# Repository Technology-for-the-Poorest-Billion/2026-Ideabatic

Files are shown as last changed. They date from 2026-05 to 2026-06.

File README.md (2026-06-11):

# IDEABATIC -Uniform Cooling Solutions

This is our team's Git Repository for our project.

Our team worked with IDEABATIC to investigate a non-uniform cooling issue within the SMILE Go vaccine carrier, a cooling device designed to transport vaccines safely in remote regions with limited access to refrigeration. Previous testing had shown that vaccines stored in the upper compartments of the carrier were consistently warmer than those in the lower compartments, potentially reducing vaccine effectiveness and storage life. To understand the causes of this temperature asymmetry, we developed a custom temperature-monitoring system and conducted a series of experiments investigating factors such as ice pack geometry, natural convection, door heat ingress, and thermal contact within the cooler. Our results showed that no single factor was solely responsible for the cooling imbalance, but that multiple interacting mechanisms likely contribute to the problem. The most effective passive solution was a redesigned ice pack insert, which reduced the temperature difference by approximately 2°C, while forced airflow using small fans almost completely eliminated the asymmetry. The findings provide valuable insight into the thermal behaviour of the SMILE Go and offer practical recommendations to support the future development of more reliable vaccine transport systems.

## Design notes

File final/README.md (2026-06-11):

# Read Me

This folder includes all the final submission work for the project. This includes individual reports, the group report, and a final video presentation.

## Other files:
- Test Results and Analysis Document
- Thermal Test Data Spreadsheet
- Final Presentation Slides
- Arduino Code for the experimental Setup
- Extensive documentation on convection, materials research, electrical work, and imaging
- CAD files for the bottle inserts

## Note of work distribution
Please note that commit history is not a representative measure of work completed by each team member. Work was collaboratively completed in a Google Drive, and group work completed uniformly between team members. A better measure of individual work would be detailed within individual reports and appropriate crediting.

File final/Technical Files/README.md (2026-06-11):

All CAD files, experimental data spreadsheet, documentation are found in here, **excluding the Test_results_and_analysis.md file.**

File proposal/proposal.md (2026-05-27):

# Problem description

**SMILE** <br>
The SMILE project aims to tackle the challenges associated with last-mile vaccine delivery and user error during transportation and administration. The “last mile” refers to the final stage of the supply chain, where vaccines are transported from storage warehouses to remote villages. Throughout this journey, vaccines must be kept within a strict temperature range of 2–8°C to maintain the cold chain. However, long transport times and improper handling often result in vaccine spoilage. Existing cool box designs present several issues that can compromise vaccine safety. In response, SMILE has been developed as a solution to protect temperature-sensitive vaccines during both transport and administration. The system features a vaccine carousel surroundings a central ice-pack bottle, all enclosed within an insulated hexagonal structure. 

Key features of the SMILE system include:
- A self-closing door to prevent the lid from being accidentally left open during vaccine administration, thereby reducing heat exposure.
- A single ice pack design, which eliminates the risk of using excessive or insufficient ice while remaining chemical-free.
- Separation between the ice pack and the vaccine chamber, protects the vaccines from freezing.

**The problem** <br>
In the SMILE, a single ice pack is used to reduce the risk of improper use and simplify operation. However, this design leads to issues of asymmetric cooling within the vaccine chambers. Thermal testing has demonstrated that the upper vaccine chambers are hotter than the lower chambers in the carousel, leading to non-uniform cooling. Since vaccines need to stay within such the narrow temperature range or 2-8°C, temperature differences will reduce the potential storage duration. By investigating the potential causes of this asymmetry and prototyping potential solutions, we can improve the reliability and extend the cool life of the vaccines. In the original SMILE, additional insulation was added at the top resulting in an asymmetric centre, to counteract heat entering from above. However, the SMILE Go (prototype we are looking at) does not use this design. We are aiming to explore alternative strategies.



# Presentation of the proposal

Through this project, we will investigate the causes of asymmetric cooling in the SMILE GO and explore ideas to reduce this temperature variation. One proposed cause of the variation is the melting behaviour of the horizontal ice pack. As it melts, the cold water accumulates at the bottom, the remaining ice floats on top and there is a air pocket at the top due to the respective densities or air, water and ice. This results in a non-uniform thermal interface to the vaccine carousel, potentially reducing heat transfer to the upper vaccines and therefore leading to the asymmetric cooling seen. Another factor we believe may cause the variation is the formation of natural convection currents within the vaccine carousel chamber.
  
To investigate these effects, thermal experiments and prototype modifications will be conducted to analyse ice melt behaviour and temperature distribution throughout the system. Potential solutions may include redesigning the ice-pack geometry, altering bottle orientation, or introducing internal thermal conduction features to achieve more uniform cooling. By reducing thermal asymmetry, the project aims to improve temperature stability and extend the effective cool life of vaccines during transport and administration.

Over the course of the next few weeks, we will:
- Design & test cooler insert with the aim of reducing the airgap at the top and redistributing the ice in the bottle
- Investigate impact of convection
- Prototype new carousel design to reduce convection

We will first test the existing prototype with temperature sensors to gain control resuts. As we propose design changes, such as the insert or the new carousel, we will perform temperature tests again to investigate if there are significant changes. We will also analyse the trade off between increasing insert volume and decreasing the water content. 

# Assessment of the quality of the proposal

In the wider context, this project will be:
- **Responsible** - The proposal should not cause any harm and we must consider any negative unintended impacts. In order to achieve this we have carefully assessed the materials we are using. We aim to use sustainably sourced or recycled materials which don’t impact workers health. For example, the icepack only contains water (no chemicals) and the icepack bottle is made of HDPE which is widely recyclable.
  
- **Responsive** - this means it responds to a genuine need. There are currently existing solutions to the problem e.g. a standard vaccine cooler, but the SMILE project is an improvement on existing coolers and our proposal would further improve this solution. Our goals and projects aims have been developed in line with talking to our partner Kitty and looking at research she has already conducted. One of the areas Kitty wants addressed is the asymmetric cooling.
  
- **Adds significant value** - Our investigation and potential solutions aim to reduce the asymmetric cooling which would reduce the temperature difference between the top and bottom of the vaccine carousel thereby allowing the vaccinces to remain within the temperature range for longer (longer cool life).
  
- **Accessible to end users** - the modifications we are making would not significantly affect usability as the changes are limited to the ice-pack bottle and the vaccine carousel design. The changes would affect manufacturing. We will keep this accessible by still using 3D printed parts and not adding significantly more parts. Any insert we design should be simple and a potential redesign of the carousel should not decrease its usability
  
- **Context appropriate** - The SMILE project is being developed for use in countries such as Cameroon where the ambient temperature is significantly hotter than the UK so the cooling aspect is more important. Additionally, the aim is for the product to be manufacturable in a makerspace in the country of use, so it should be 3d printable and use accessible materials.

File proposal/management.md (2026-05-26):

# Project Management Plan

## The People
The three members in our team are Karen, Kerry, and Kavita:

Karen (mechanical/electrical engineer)
- Strengths: 3D modelling,3D printing, Drawing
- Weaknesses: Thermal modelling, Hardware

Kerry (mechanical/aerospace engineer)
- Strengths: Thermal/material knowledge, Mechanical design
- Weaknesses: Computational modelling, Electronics

Kavita (mechanical/electrical)
- Strengths: Electronics, 3D printing experience
- Weaknesses: Computational modelling

## The Resources Needed
| Resource | Cost | Source |
|---|---|---|
| PLA printer filament | £10–15 | CUED |
| Ice Bottle | £10 | RS Components |
| Temperature Sensors | £25 | Amazon |
| Arduino Wires | £0 | CUED |
| Laser Cut Wood (Offcuts) | £0 | CUED |
| Hot Glue Sticks | £1 | CUED |

## The Timeline
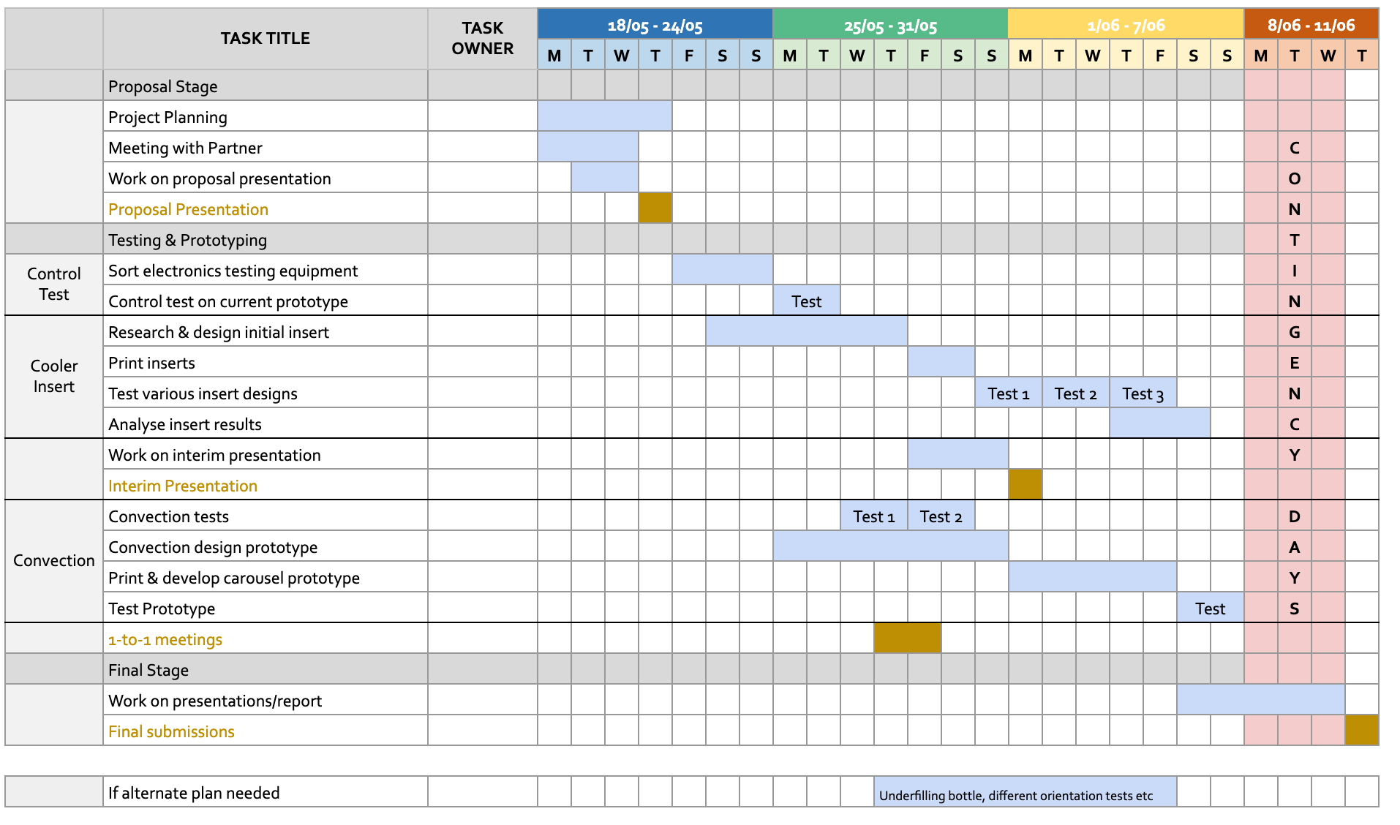
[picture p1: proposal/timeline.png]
Timeline


## Contingency Plans
Our approach to contingency involves a variety of strategies. 
#### Extra Time:
Firstly, extra time has been included in the development timeline at the end of the project. This means that, in the case of delays or unexpected issues during the course of the project, our timeline is be flexibile enough to allow the team to finish any required work on time. This is particularly useful since the plan is to operate a continuous sequence of experiments - any hiccups may lead to cascading delays. The contingency days overlap with the report-writing period, as the work can be carried out flexibly alongside other tasks.

#### Staged Testing Approach:
An important consideration for this experiment-driven project is ensuring that progress is not entirely dependent on a single test outcome. As an example, early in the testing phase, an experiment will be conducted to assess the significance of convection in causing non-uniform cooling. If convection is found to have a substantial effect, the next stage of the project will focus on designing a new vaccine carousel to mitigate natural convection within the cooler. If the effect is minimal, a contingency plan will be implemented involving further investigation into other factors that may contribute to non-uniform cooling. This staged testing approach ensures the progress of this project does not falter given a certain test result.

#### Other Ideas to Investigate:
Given the minimal impact of cooler inserts or convection prevention, some further investigations can be conducted, to provide Kitty and IDEABATIC more information on the SMILE Go. These include:
* The effect of underfilling the bottle - investigating the effect of a larger air bubble on non-uniform cooling.
* Insulation methods and materials - investigating cheap and viable alternatives for SMILE Go manufacture.

#### Reduce risks:
Finally, to avoid project failure for safety reasons, and to maintain teammembers' safety, all members will produce and sign risk assessments for the tools and methods to be used in this project. 

## The Assessment of the Risks and Safety Considerations
### Tooling Risks
#### Effect
* Burns from hot glue guns
* Soldering burns, breathing in toxic fumes
* Fire from laser cutter
* Cuts and incidents from hand tools
#### Mitigation
* Acquire appropriate training
* Make sure fume hood on laser cutter is activated
* Keep hands and skin away from hot surfaces

### Electrical Testing Risks
#### Effect
* Water contact with electrical components
* Overheating of Arduino
#### Mitigation
* Keep electronics away from water
* Keep surfaces dry
* Keep voltages and currents within working range

### 3D Printer Risks
#### Effect
* Cuts from sharp components from 3D print
* High temperatures on 3D printer nozzle
* Fingers or clothes getting caught in moving parts
* Toxic fumes from print material
#### Mitigation
* Maintain distance from 3D printer as it is operating
* Use non-hazardous materials in 3D printer

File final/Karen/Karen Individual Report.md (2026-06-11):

# Technology for the poorest billion

# SMILE GO Project - Uniform Cooling Solutions

Karen Miyazaki | 11 June 2026

## Project Team:

Karen Miyazaki, Kerry Dai, Kavita Sivaraman

## In collaboration with:

Kitty Liao, Oliver Griffiths

# My Contribution

This report documents my contribution to the SMILE GO project, which investigated the causes of non-uniform cooling within the vaccine carrier and explored potential methods to reduce the temperature differences within the cooler carousel. My primary responsibility was the design, manufacture and evaluation of bottle inserts for the central ice pack. As a team, we all contributed to experimental setup, test execution and analysis throughout the project. Ideas for tests were discussed as a team and set up together upon reaching an agreement.

# Project Overview

The SMILE GO is the scaled down version of the SMILE vaccine cooler created by Kitty Liao’s company, Ideabatic, which helps deliver vaccines to remote and low-resource areas. The cooler is designed to be an affordable and portable solution, making it more suitable where access to reliable refrigeration and healthcare infrastructure is limited such as in Cameroon. The vaccine cooler is required to stay in a 2-8 degree temperature range to maintain the cold-chain. If the vaccines go below 2 degrees, there is a risk of the vaccines freezing and likewise if the vaccines go above 8 degrees, there is a risk of the vaccines denaturing.

However, it was observed that the upper chambers inside the cooler were much hotter than the lower chambers so we aimed to identify the causes of non-uniform cooling within the vaccine cooler and propose mitigation strategies for this. This investigation is crucial to ensure that all vaccines safely remain in range to ensure the vaccines remain effective for a longer period of time. Vaccine wastage can also be reduced, making healthcare delivery more reliable and sustainable in these rural areas. Throughout this project, we collected valuable thermal data that can be used to inform future design improvements.

# Prototyping set-up

## Insert Development

Upon discussion with Kitty, we hypothesized that the ice pack cools unevenly because of the large internal air gap at the top of the ice bottle during melting. Since air has a much lower thermal conductivity than water, the air gap at the top of the bottle was expected to act as an insulating region. This would reduce heat transfer from the upper vaccine compartments to the remaining ice or meltwater, leading to higher temperatures in the upper compartments.

I designed the inserts to divide the bottle into multiple chambers while maintaining a simple geometry that could be manufactured using FDM 3D printing. I generated multiple insert designs and evaluated them before a final design was selected. The design process focused on balancing thermal performance with practical manufacturing constraints. The insert needed to fit through the bottle opening, maintain sufficient internal volume for the ice pack, and be manufacturable using the available 3D printing facilities. A few packaging methods were considered such as snap-fit inserts, slotted structures or single print structures. These ideas are presented below:

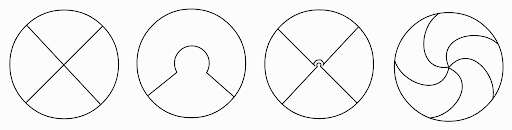
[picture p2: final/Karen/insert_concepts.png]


The first design was selected due to its simplicity and reliability. In this set-up, the two planes have slots that physically interlock, allowing the print to be done as two flat planes instead of a thin 3D part. Two planes were sufficient to demonstrate results, while remaining practical to insert into the bottle. As shown in the diagram below, the larger air gap gets segmented into four chambers, so the upper chamber has less insulation from the air in this set up than without the inserts.

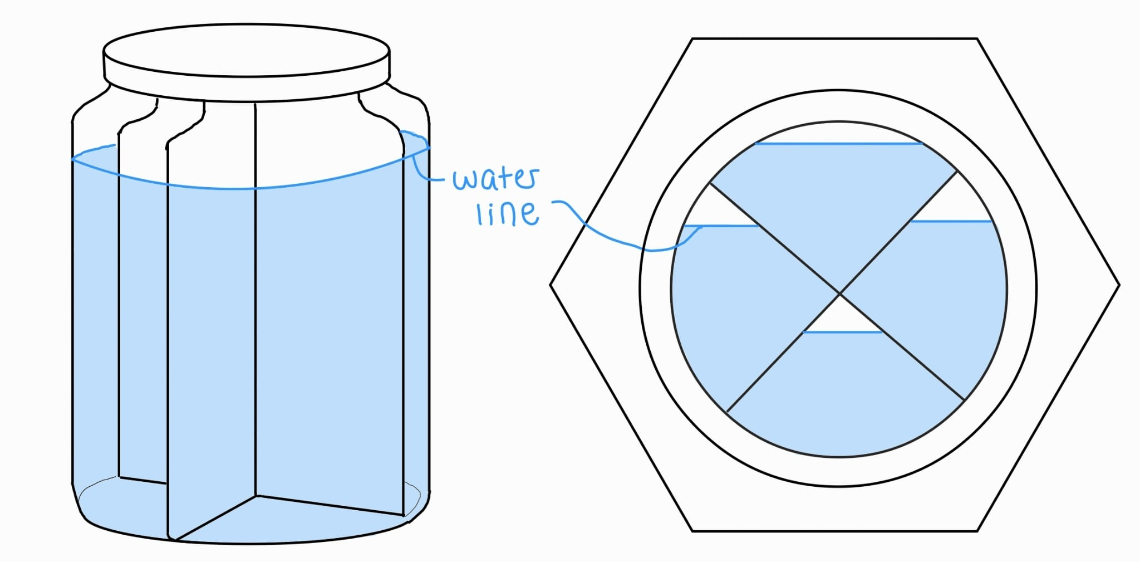
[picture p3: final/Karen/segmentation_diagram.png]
 

However, this design relies on the 3D print being flexible enough to push through the neck of the bottle. Therefore, an initial prototype was produced to verify fit and assembly within the bottle. The inserts were manufactured using PLA through 3D printing. Printing parameters of 100% outer walls and 15% infill provided adequate stiffness while retaining a small degree of flexibility during assembly. This is shown below:

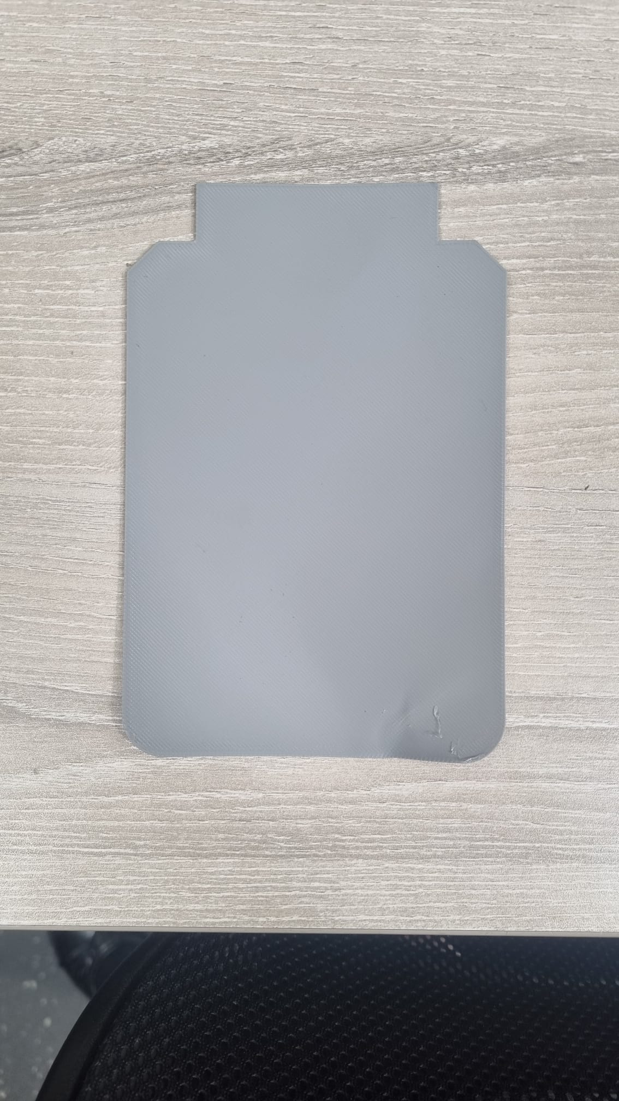
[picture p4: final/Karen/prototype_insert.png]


Early testing demonstrated that attaching the insert directly to the bottle lid was impractical due to difficulties associated with the screw closure mechanism. As a result, the design was modified to incorporate a separate printed top section. Two further iterations were completed to refine the dimensions and ensure reliable closure of the bottle. The final design successfully allowed the bottle lid to close while maintaining the required internal geometry. These designs are shown in the CAD models below:

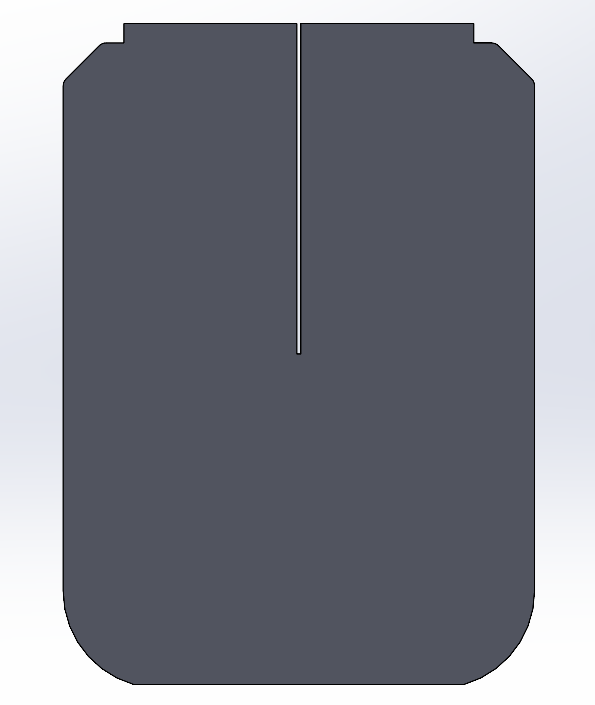
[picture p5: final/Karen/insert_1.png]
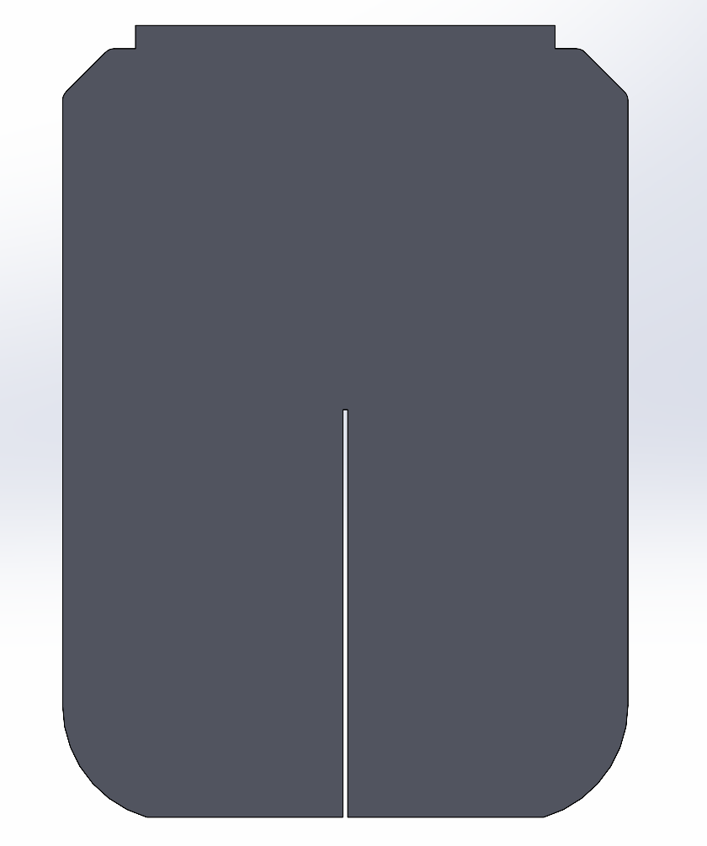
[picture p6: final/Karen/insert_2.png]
  

Throughout the design process, several practical limitations of this prototyped design became apparent, particularly regarding print porosity and sealing.

## Assembly

A significant challenge encountered was producing a watertight and airtight seal within the bottle. Hot glue was selected as a low-cost and readily available sealing method for prototype testing. Kerry was responsible for hot gluing the insert into the bottle and additional hot glue was applied around the interfaces to minimise leakage. I assisted with this process at times. The assembly is shown below:

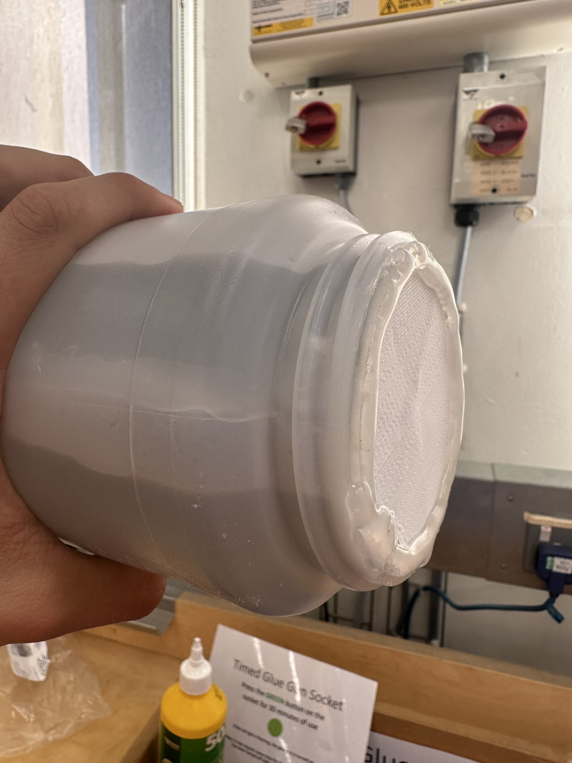
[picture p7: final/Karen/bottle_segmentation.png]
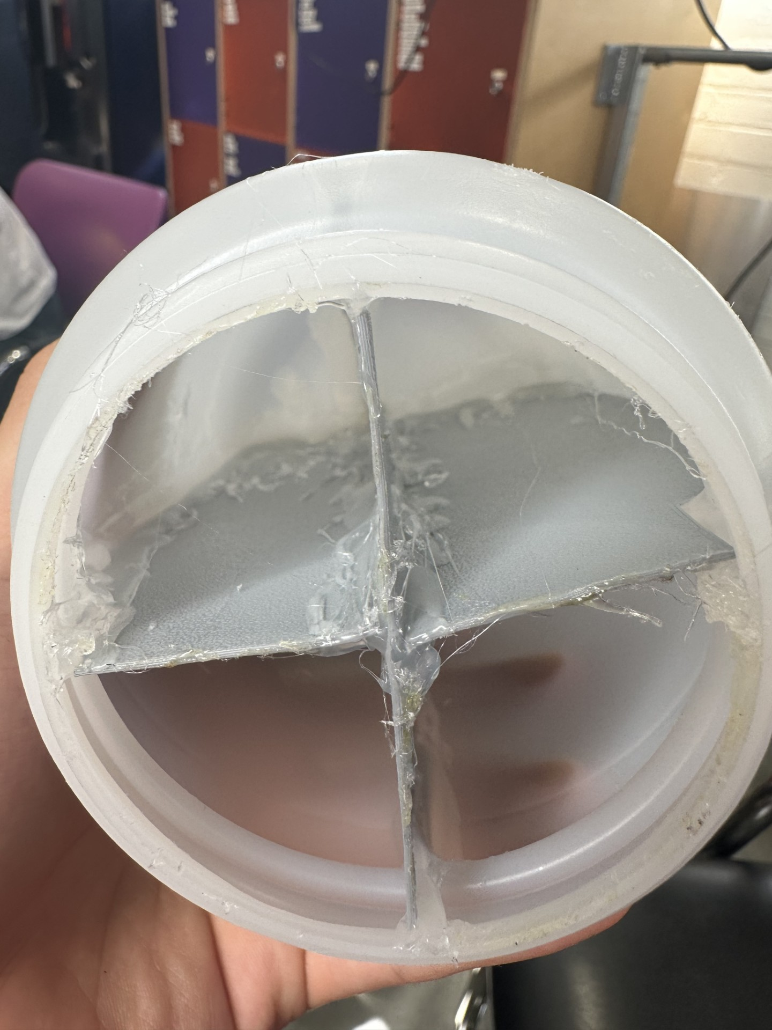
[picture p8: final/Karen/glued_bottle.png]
 

Following assembly, the bottle underwent a freeze-thaw cycle prior to experimental testing. The insert and adhesive joints remained structurally sound throughout this process and the final assembly was found to be almost perfectly watertight and airtight.

## Materials research

Throughout the design process, Kerry and I analysed the materials used in this test in the [Material research](../Technical%20Files/Research%20and%20Documentation/Materials%20Research/Materials%20research.md) document. Several limitations of 3D printing became apparent, particularly regarding print porosity. Moisture permeation was observed through some printed components caused by microscopic voids and gaps between extrusion lines. This was more significant in the earlier prototype, which was printed using a lower-precision printer. Later prototypes were produced using a higher-quality Bambu Lab printer with 100% top and bottom densities and 15% infill. This improved print consistency, reduced visible porosity, and still retained enough flexibility for the insert to be pushed through the bottle neck during assembly. Over time, this may still pose as a concern.

PLA was suitable for rapid prototyping because it was cheap, quick to manufacture, readily available in the Dyson Centre, and allowed complex geometries to be produced easily. However, it is not ideal for long-term use in the SMILE GO cooler. The material PLA itself can absorb moisture over time and may undergo hydrolytic degradation in water. Repeated freezing and thawing may also cause the absorbed water within the print to expand and contract, potentially opening cracks or weakening the interfaces between printed layers. For the short duration of our prototype testing, these limitations were acceptable, but they would be problematic for a cooler intended to last for several years.

Sealing the inserts inside the bottle also presented practical difficulties. Hot glue was selected because it solidified quickly, was low cost, and could be removed relatively easily, making it suitable for iterative prototype testing. However, it is not a reliable long-term sealing method. The bottle is made from polyethylene, which hot glue only bonds to weakly, and the adhesive may become more brittle during freezing. Repeated freeze-thaw cycles could therefore cause the hot glue to debond from either the PLA or the bottle wall, allowing water or air to pass between chambers.

I identified PETG as a more suitable material for future 3D printed prototypes, as well as for the carousel that becomes wet due to condensation. It has lower water absorption than PLA, is more water resistant, and is less brittle at low temperatures. This would make it better suited to a water-filled component undergoing repeated freeze-thaw cycles. However, PETG was not available in the Dyson Centre during the project, so PLA remained the most practical option for the tested prototypes.

Alternative sealing methods were also considered. Epoxy coating could improve the waterproofing of printed PLA parts, but its long curing time made it unsuitable for our project timescale. I identified silicone sealant to be more appropriate for long-term sealing because it remains flexible at low temperatures and can better accommodate differential thermal expansion between the bottle and the insert. However, its curing time is also much longer than hot glue, so it was less convenient for rapid prototyping.

# Testing

The electronic set up to obtain data from four temperature sensors was made by Kavita, where two probes measured the upper compartments and two measured the lower compartments. A control test was conducted with the original set up to serve as a baseline for our tests.

As a team, we thought of potential reasons for the asymmetrical cooling and subsequently set up experiments together to run. These tests and results can be found in the [Test Results & Analysis](../Test_results_and_analysis.md) document. Other than the insert test, a number of additional tests were completed. One investigated the effect of the base of the ice pack being in contact with the carousel by inserting small sticks into the gap between the two components. Another was run to understand the role of convection in the thermal data, which involved ten cardboard radial planes slotted into the carousel. The edges were sealed with duct tape to ensure no air could pass between the compartments on the carousel. The tests we performed progressively evolved as we obtained data, requiring the inserts, convection planes and sticks to be installed multiple times. Each was compared against the control tests 1 and 2 depending on the ambient temperature in the experiment.

The insert was subsequently incorporated into the combination tests alongside other mitigation strategies. These combined approaches produced further reductions in temperature difference compared to the insert alone, suggesting that multiple factors contribute to the observed non-uniform cooling.

# Results

The insert test demonstrated that partitioning the ice pack into multiple chambers reduced the temperature difference within the vaccine compartment. At 12 hours, the temperature difference between the warmest and coolest measurement locations decreased from approximately 7.2°C in the control test to 5.3°C with the insert installed, representing an improvement of around 2°C. The results suggest that the distribution of ice, meltwater and air within the bottle influences the overall cooling behaviour of the SMILE GO cooler. The graphs can be seen in the [Test Results & Analysis](../Test_results_and_analysis.md) document attached in this github.

Although the temperature difference was reduced, substantial variation remained throughout the test, suggesting that the air gap within the bottle is unlikely to be the sole cause of the non-uniform cooling. The results are consistent with the hypothesis that segmentation of the air gap may influence the cooling behaviour of the system. However, the observed improvement was relatively small and the ambient temperature fluctuated throughout the experiment, affecting the temperatures measured within the carousel. Therefore, it cannot be concluded with certainty that the reduction in temperature difference was solely attributable to the inserts, and further testing under more controlled conditions would be required to confirm their effect.

The inserts were subsequently incorporated into the combination tests alongside other modifications, including improved thermal contact and radial planes intended to reduce convective air movement. These combined interventions produced greater improvements than the insert alone, suggesting that multiple heat transfer mechanisms contribute to the observed temperature gradients. This finding indicates that future design improvements should consider the combined effects of ice pack geometry, thermal contact and convection rather than treating each factor independently.

The in-depth data and analysis of the remaining tests are in the [Test Results & Analysis](../Test_results_and_analysis.md) document attached.

# Conclusions

The objective of the insert development programme was to investigate whether segmentation of the ice pack could reduce the non-uniform cooling observed within the SMILE GO vaccine carrier. The insert tests showed a reduction in temperature difference between the upper and lower compartments. However, the improvement was relatively small and ambient temperature fluctuations during testing make it difficult to determine how much of this change was caused by the inserts themselves. 

The inserts did not eliminate the asymmetry entirely. Subsequent testing showed that additional mechanisms, particularly natural convection within the vaccine chamber and the thermal contact between the ice pack and carousel, also contribute to the observed temperature gradients. The insert should therefore be considered a partial mitigation strategy rather than a complete solution. This reinforced the need to investigate additional reasons for this non-uniform cooling.

The project also highlighted the importance of considering manufacturability alongside thermal performance. Although PLA inserts and hot glue seals were suitable for rapid prototyping, several limitations were identified regarding porosity, moisture absorption, durability and sealing reliability. These factors are unlikely to significantly affect short-term testing but would present challenges for long-term deployment.

Overall, the insert design was suitable as a proof-of-concept prototype, but not as a final production solution. For small-scale use, improved 3D printed inserts using PETG and a more durable sealant could be investigated. For larger-scale manufacture, a more robust approach would be to eliminate the separate inserts and adhesive joints entirely by producing a bottle with integrated internal chambers, for example through extrusion blow moulding or stretch blow moulding. This would improve durability, watertightness and reliability over the 10 year service life of the cooler.

# Recommendations

Although the insert tests indicated that modifications to the internal air gap may influence the cooling behaviour of the SMILE GO system, the observed temperature differences were relatively small and the experimental conditions were not perfectly controlled. Future work should therefore investigate alternative insert geometries and chamber arrangements to determine more conclusively whether modifications to the internal air gap can improve cooling uniformity. Additional testing should also be conducted to evaluate the influence of chamber size, air gap distribution and amount of 3D print used on thermal performance.

For future prototypes, PETG should be considered in place of PLA due to its improved water resistance, lower moisture absorption and better resistance to low-temperature embrittlement. Alternative sealing methods such as silicone sealant should also be investigated to improve durability during repeated freeze-thaw cycles.

Further testing should be performed under more controlled environmental conditions and over longer timescales to better replicate real operating conditions. Repeated freeze-thaw cycling would be particularly valuable for assessing the long-term reliability of both the insert and the sealing method. The cooler used for testing was broken from long-term use and drop-tests, so using a better sealed cooler would be useful.

# References

ChatGPT used for formatting and grammar

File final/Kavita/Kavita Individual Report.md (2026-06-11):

# Technology for the Poorest Billion: Ideabatic – Uniform cooling team
## Kavita Sivaraman
**Working with Kerry Dai & Karen Miyazaki**

## Report Overview
This report provides an overview of the whole project and the key issue of non-uniform cooling within the vaccine cooler. It describes the design and  implementation of the electrical test setup, which was my main individual contribution. In addition, all experimental testing and data analysis was completed collaboratively as a team. Therefore, this report provides a brief summary of the results and findings, but for further detail, refer to the test results document.

## Intro
Vaccines face the logistical challenge of needing to remain within a narrow temperature range  of 2-8°C to remain effective. This presents a challenge for delivering vaccines to remote villages in countries such as Cameroon, where access to reliable electricity is limited. The SMILE project has been developed to address this challenge of maintaining vaccine efficacy for ‘last mile’ vaccine delivery. 

Earlier this year, a thermal test conducted by our partner Kitty on the current SMILE Go prototype showed a significant temperature gradient across the vaccine carousel (as can be seen in the figure below), with compartments at the top of the carousel being hotter than those at the bottom. Given the narrow temperature range within which vaccines must be stored, this non-uniformity limits the cool life and increases the risk of spoilage. 
 
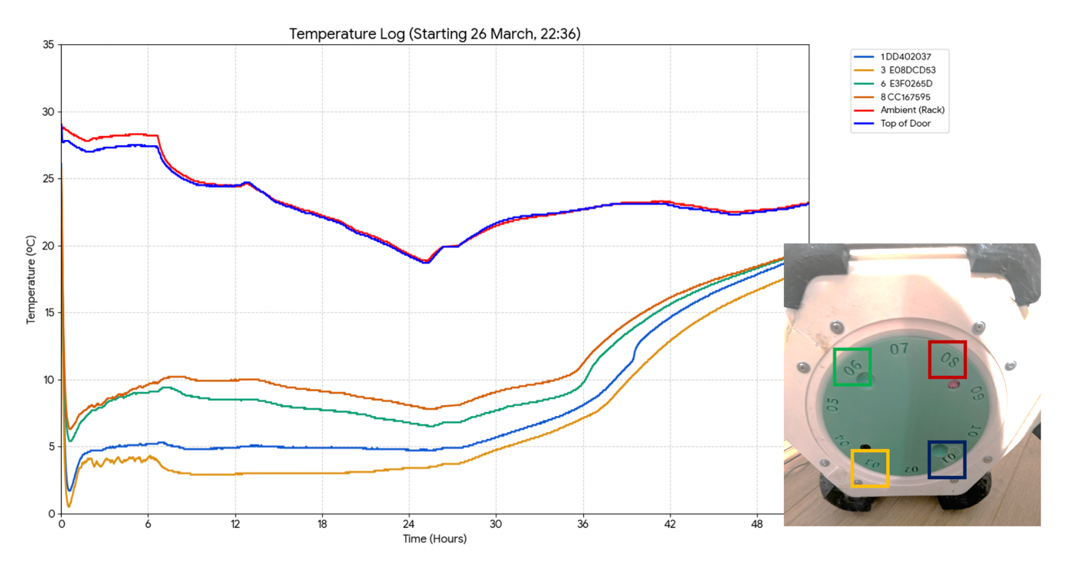
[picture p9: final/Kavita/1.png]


## Project direction
We decided to investigate this non-uniform cooling issue due to the limited understanding of the underlying causes. We initially considered completing a combination of thermal modelling and experimental testing. However, after consulting with our partner, we decided against including thermal modelling within our scope. Some basic modelling has already been completed in previous years’ projects, and developing a more realistic model would require significantly more time, thermal expertise and resources than we had available. As a result, we focused on conducting actual experiments to investigate potential variables that could be contributing to the formation of a temperature gradient. 

In the beginning, we intended to solely investigate the impact of cooler inserts and convection (as can be seen in our original Gantt chart). However, as testing progressed, we identified additional variables that we believed could be influencing the thermal distribution in the cooler. This included heat entering through the access door and the non-uniformity of the contact between the ice bottle contact and the carousel.

Designing Test Setup & Electrical information

Given that our project involved investigating the thermal non-uniformity in the vaccine cooler, it primarily consisted of conducting a series of thermal tests, typically lasting between 6 and 30 hours. I was responsible for designing the test setup, as I had interest in and some previous experience with electronics. I first identified our test system’s requirements, based on the need to compare our results with those obtained by Kitty earlier this year and to allow comparison and therefore evaluation of the effects of the different variables we tested. Kitty’s test had used Bluetooth temperature sensors, with 2 placed in the upper vaccine chambers and 2 in the lower vaccine chambers. She had attempted to use a temperature-controlled chamber, but this had failed midway through her experiment. 

Our system needed to measure the temperatures at multiple locations in the carousel, timestamp the data, store the data and allow the frequency of measurements taken to be adjusted.

We initially planned to use Kitty’s Bluetooth sensors as they had a resolution of 0.1°C and were wireless. However, these could not be located, so I evaluated alternative options based on cost, accuracy, availability, physical size, and circuit requirements and decided on the DS18B20 temperature sensors, which had an accuracy of 0.5°C. The temperature sensors were daisy chained and connected to 5V by a 4.7 kΩ pull-up resistor.

As a result, I developed a test setup using an Arduino connected to 5 temperature sensors, an SD card module for data logging and power source.  My initial plan was to power the Arduino through a PC, which would also allow real-time monitoring through the serial monitor and could therefore provide verification that the test was working correctly at the start, whilst simultaneously storing our data.
I also developed a backup power plan in case we did not have access to Dyson centre computer overnight. This consisted of 6xAA batteries, a barrel jack connector and an RTC module. 

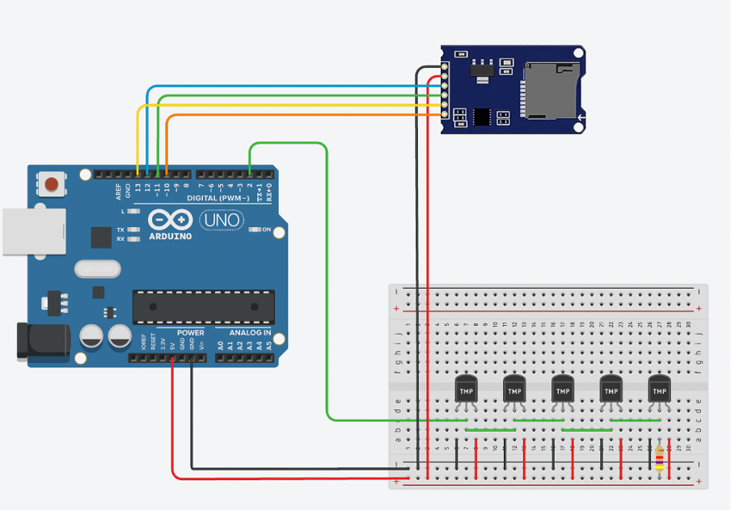
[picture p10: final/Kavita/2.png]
 
 
_Electrical circuit diagram made in Tinkercad circuits_

The sensor arrangement consisted of four sensor probes placed within the vaccine carousel (two in upper compartments and two in lower compartments) and one sensor placed out of the cooler for ambient temperature measurement. All sensors were mounted on foam and secured with tape to ensure consistent positioning and comparable height across compartments. The SMILE Go was tested horizontally in a spill tray to mitigate risk from leakage. See the images below to see the test setup.

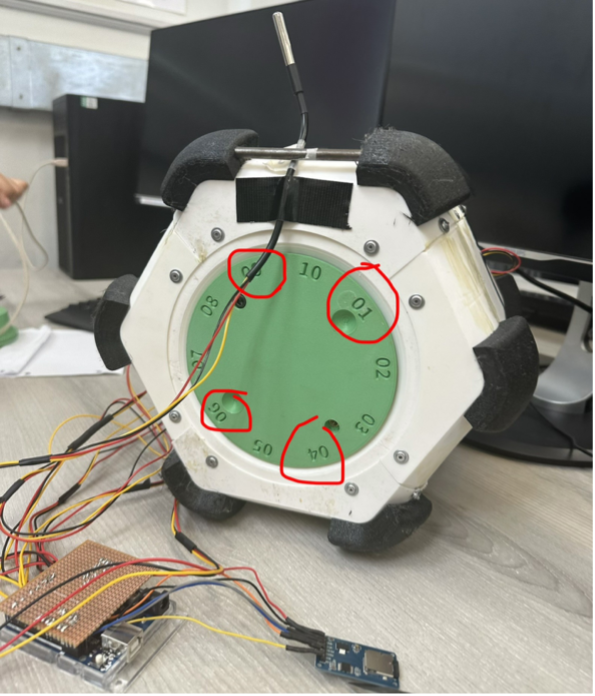
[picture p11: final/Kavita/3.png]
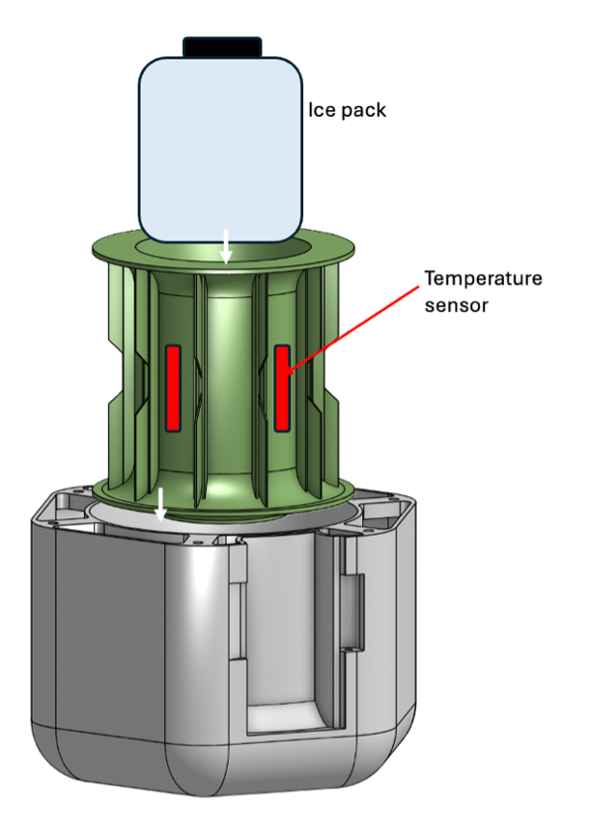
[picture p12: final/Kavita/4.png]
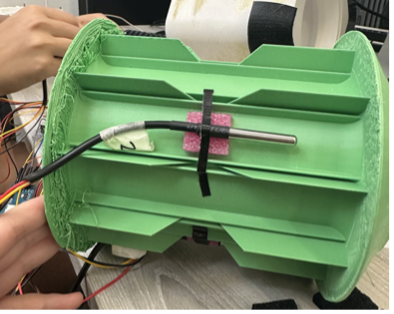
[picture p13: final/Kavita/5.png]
   

Each test used this general test setup and then we made changes to the prototype or icepack. Karen researched into cooler insert material and design and both Karen and Kerry were responsible for implementing those changes on the bottle.

I first breadboarded the circuit and ran code to test the individual components before then soldering the circuit as breadboarded circuits are quite temperamental and given that we would be reusing this circuit a lot it made sense to make it more sturdy. After making sure the test equipment worked, I conducted a test equipment experiment to run overnight to check the equipment worked over several hours and to make sure the dyson PC would provide power overnight.

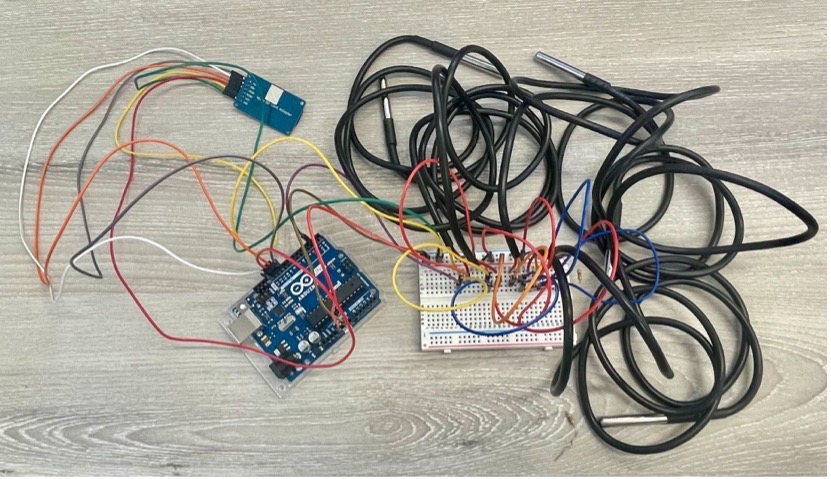
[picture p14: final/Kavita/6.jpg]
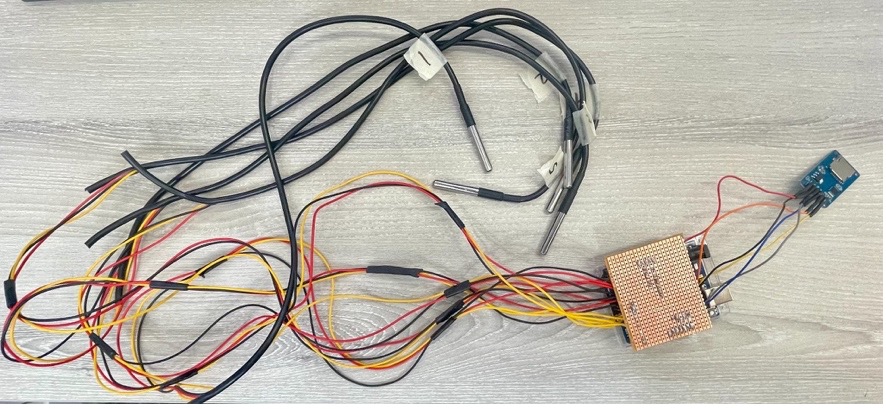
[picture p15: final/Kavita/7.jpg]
   
  
_Initial breadboarded circuit & Soldered circuit_

## Code
The code was written by combining code for multiple DS18B20 temperature sensors available on their data sheet and the standard code for printing to an SD card. The libraries you need to download for the temperature sensors are dallasTemperature and OneWire. The libraries needed for reading and writing to the SD card are SPI & SD.  To see the full code, see git pg…

## Assessment of electrical monitoring system

Overall, the electrical temperature monitoring circuit performed very well. It provided reliable temperature data from all 5 sensors to an appropriate level of accuracy in every test.
There was one instance in which, at the start of a test, the code produced an SD card error message when the cooler was moved to the tray. This led me to discover a loose SD card module wire, which required resoldering. Aside from this incident, no further resoldering or circuit modifications were required.

However, I did face significant issues in getting the Arduino to connect to the computer and then in running the code on the Arduino. This occurred because I had initially been using an Arduino clone board found in the Dyson Centre. This board worked sometimes; however, most of the time I just got error messages. I rectified the situation by first changing the Arduino power/data wire, which had no effect, until I changed the actual Arduino Uno to one that was not a clone.

(I have compiled all this information into a document called ‘Electrical’ which is also accessible through the Git website and is in an appropriate handover format

## Tests 
For our investigation, our team conducted a series of tests to narrow down the causes of the non-uniformity. We conducted:
-	2x Control tests – tests run to compare against our following test results allowing analysis of the changed variable
-	Door oriented downwards – cooler orientation was flipped such that door was on bottom. The door is a potential area where heat could be entering as it is poorly sealed.
-	Cooler insert test – 3D printed PLA insert in the shape of a cross inserted to split the ice into chambers
-	Top Contact test – raised the icepack off the bottom of the bottle chamber so that the ice was now in contact with the top.
-	Vertical – solution based test. Oriented the cooler upright.
-	Convection test (as well as additional tests to assess our setup) – inserted radial baffles
-	Fan test – solution based test. Attached 2 fans to carousel to force air around.
-	Combination tests – both top contact and convection tested

At the beginning of every test, I made sure the code uploaded correctly and checked that the temperature sensors were being read as well as that the data was being correctly stored to the SD card.
During the test, every so often, I would look at the serial monitor to monitor the test.
At the end of every test, I then read the txt file from the SD card and compiled it into a graph which could then be analysed by myself, Kerry and Karen.

## Insert tests
Karen was responsible for researching, designing and then 3D printing cooler inserts for us to test in the ice pack bottle. Kerry (and Karen) were responsible for inserting the insert and attempting to make it watertight using hot glue. The inserts were 3D printed in PLA, as this was the main print material we had easy access to. However, research was conducted into other materials and sealants to be used, as hot glueing, whilst fine for prototyping, is not suitable for manufacturing.
Ice pack inserts were an idea our partners were keen for us to look into. The idea behind an insert is that normally, as the ice melts, the cold water would sink to the bottom of the bottle, the ice would float in the middle and then the air would accumulate at the top of the bottle. This could therefore be a factor contributing to the non-uniform cooling. By putting an insert into the ice bottle, this would keep some of the ice and cold water in the top of the icepack bottle when it laid horizontally.

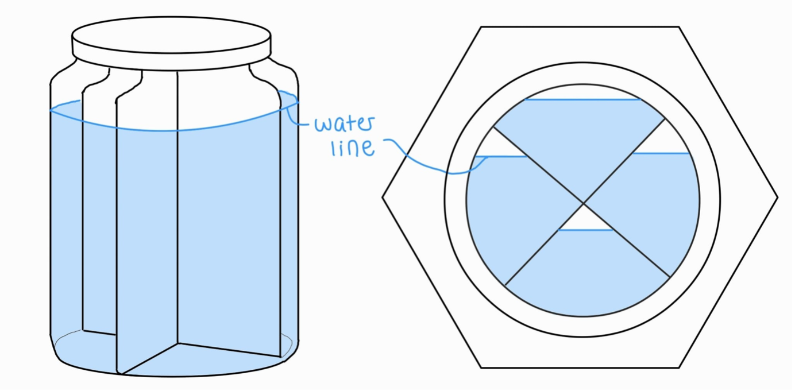
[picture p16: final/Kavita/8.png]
  
  
Diagram made by Karen

## Convection tests
From our tests, it became apparent that cold air was accumulating at the bottom of the carousel while hot air was rising, resulting in the observed temperature gradient. Given that the data showed this gradient forming very quickly, it seemed unlikely to be caused solely by the geometry of the ice melting (the issue targeted by inserts), and we suspected natural convection might be responsible. Kerry researched this idea, and we decided to conduct a test using tightly fitting radial inserts to seal off the individual chambers of the carousel. This would prevent or at least slow down (since not properly airtight) the movement of hot air upwards and the cold air downwards. The results showed a slight reduction in the temperature gradient, but not as much as expected. As a result, I proposed conducting a further test to evaluate the effectiveness of our convection setup. This was done by placing a small bag of ice in the top compartment, both with and without the radial convection setup, to observe how quickly cold air would sink to the bottom of the carousel. Our results did show that the setup had an effect on the convection. However, because a much smaller amount of ice was used, the rate of temperature decrease was significantly lower than in a normal test, so it could not provide an accurate sense of the timescale if using the central icepack instead.
 
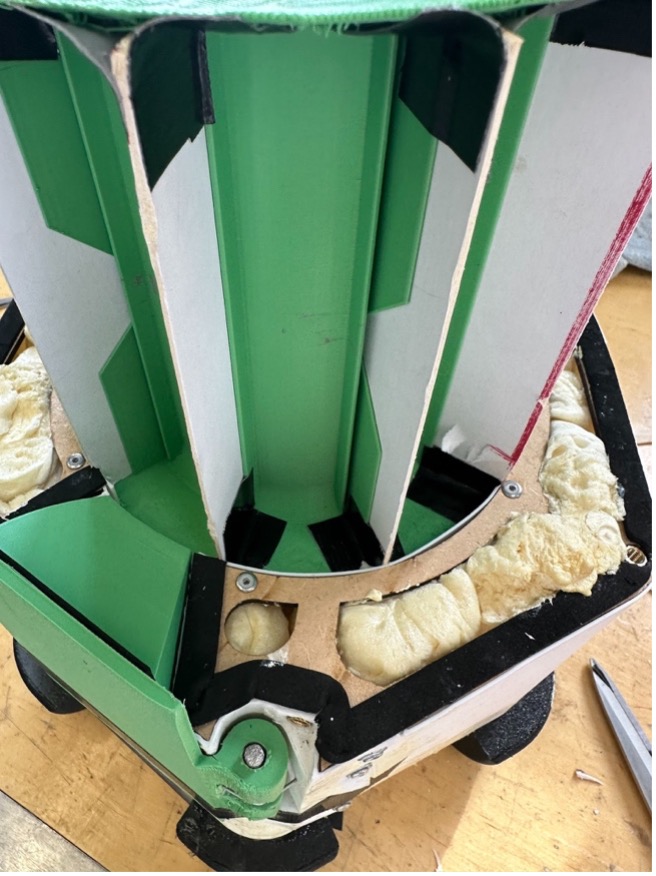
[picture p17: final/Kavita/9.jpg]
 
 
## Assessment of Tests
Given the nature of the tests and our ability to control certain variables, there were certain things about our setup that were not ideal and may have affected the validity of our results.
Ambient temperature not being controlled: All our testing was conducted in the Dyson centre rather than a temperature controlled environment. The temperature within Dyson was not constant but stayed within a few degrees in a 24hr cycle. This was already a significant improvement on Kitty’s test which had a temperature range of 18 – 28 °C as the temperature chamber she had initially been using to test the device at 28°C stopped working. However, our testing did show that the ambient temperature significantly effected the cooler’s internal temperatures, leading to rises and drops as per the ambient.
Prototype condition: The prototype SMILE Go we were testing on had been drop tested during last year’s project. As a result, some of the rivets were starting to become loose and the door hinge did not correctly fit into its slot. These factors could have affected the insulation and sealing of the cooler. We tried to account for these factors, where we thought it might lead to particular hotspots like the door, which we tested by monitoring the cooler upside down with the door on the bottom instead.

## Feasibility of using a fan
The fan test was a more solution-oriented test rather than investigative. It did not necessarily narrow down what was causing the non-uniformity, but showed that forced convection stopped the temperature gradient. 
This is not the ideal solution because the cooler is currently passive. Therefore, using an active system which requires electricity like the fan concept is not ideal. However, adding an electronic component is not without precedent, as past projects have developed electrical monitoring add-on packages.  Therefore, an active solution could be feasible. The fans we used in the experiment were 25x25x10mm DC 5v brushless fans. These fans were incredibly small and had a max operation of 3400rpm with an air flow capacity of 0.027 Cubic metres Per Minute.
Electrical details: 5V, 0.02A, 0.1W
This is actually a very low power fan, so it would not be unrealistic to power this for the necessary 24hrs.
For 24hrs, the energy required by the fan: E = P x t = 0.1 x 24 = 2.4 Wh
So for 2 fans this would be 4.8 Wh of stored energy.

Potential power sources include:
-	4xAA batteries: provide ~6V, ~2500 mAh, 15Wh
o	An alternative to reduce the number of batteries is to use just 1 or 2 AA batteries as they can provide sufficient current and power to the fans, but a boost converted would be required to raise the voltage to 5V.
-	A 18650 Lithium ion cell: ~3.6V, 1500 – 3500 mAh
o	This would also require a boost converter to provide 5V
These are both cheap, readily accessible potential power sources that can easily last a full journey. They would experience loss of performance in high temperatures but it should not be an issue
-	Solar cell: 
o	The solar cell would need to be connected to a rechargeable battery which could then drive the fans. This circuit could have losses of up to 20% so 5.76Wh required.
o	A 1-2W solar cell should be able to charge the necessary batteries with a few hours of sunlight.

## Test results and discussion 
Our group’s main technical output was our thermal monitoring tests and the results we obtained. This testing and the results analysis was completed by our whole team and cannot be distinguished. As a result, to avoid repetition in each of our individual reports, please see the markdown page called ‘Test results & analysis’ for our test results.

## Further testing & potential design changes
Based on our tests, the most important design changes to make to the current prototype are improving the insulation. This is critical given that in every test our temperature sensors showed that the top compartments were above the required 8 degrees. The current prototype uses spray foam and is very unevenly distributed. 

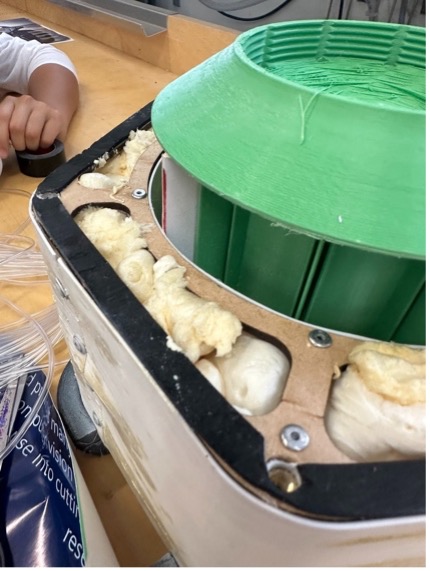
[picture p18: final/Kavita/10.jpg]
 
 
Looking at our control tests done at different ambient temperatures and the resulting temperatures the compartments stabilised at, also suggests improving the insulation would help keep the vaccines below 8 degrees and would likely reduce the temperature difference. This insulation could be manipulated to reduce the temperature gradient by adding more or better insulation to the top. This asymmetric insulation concept is employed successfully by the original SMILE. Other alternatives could include adding an additional icepack to the top of the cooler, by the door.
Additionally, almost all of our tests showed the bottom compartments going well below 2°C into the freezing range which is not acceptable for vaccines. This suggests changes need to be made to the carousel design such that the 3D print is thicker or other insulation is added in some other way. Adding fins all the way around the interior of the central chamber so that the ice pack bottle isn’t in the direct contact with the walls, could prevent this freezing and would also solve the non-uniform contact issue.
Both solution-oriented tests we conducted showed great promise. The forced convection test with the fans successfully brought the compartments to within the range and led to almost uniform conditions across the carousel. Based on my feasibility calculations above, it would not be too difficult to implement if active solutions were to be considered. The other solution based test was the vertical orientation test. This showed only a 1°C difference between compartment locations at the bottom and top of the icepack (see sensor 2 & 4 in the figure below). However, this test was only conducted for 5.5hrs and the ice pack does not extend to the top of the carousel, so the temperature measured there (sensor 1) was several degrees warmer. It would be worthwhile testing this same setup with a taller icepack and over a longer duration, as this could be a very simple solution if it continued to show such promising results.
 
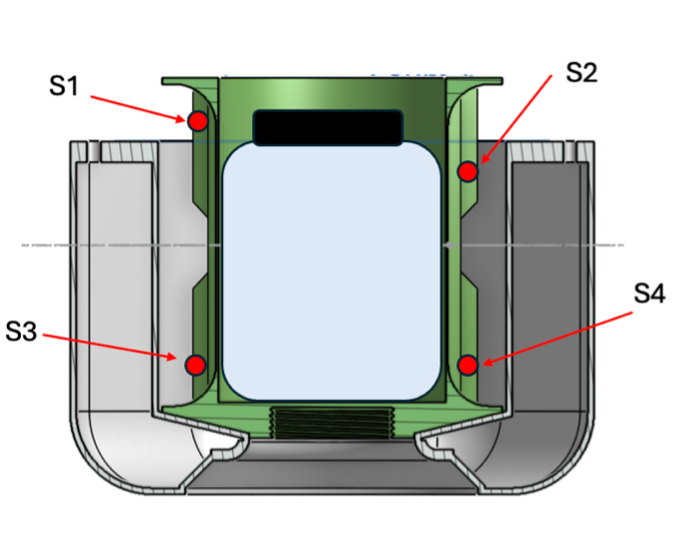
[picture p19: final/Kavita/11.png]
 

## Reflections
This project gave me the opportunity to engage with technical areas such as electronics, practical testing, and data analysis. It was also a valuable opportunity to work in a team, figuring out the most effective way to collaborate, divide the workload and manage our limited time effectively. 
One important lesson I learned was the need to be adaptable. This became apparent at the outset, when our electronic component procurement took longer than expected, delaying our testing schedule. However, we continued to adapt throughout our project, as we modified the tests we conducted and therefore the schedule in response to new ideas and theories we thought of as the project developed.
One aspect that differed from my expectations was that I expected to find one factor which would not show any or very little asymmetry i.e. find a dominant cause. As a result, some tests were run for shorter periods than would have been ideal so that we could get through more tests because we thought a few hours was enough to determine if that was the dominant cause. However, given that the results suggest the asymmetry is most likely due to a combination of factors, it would have been beneficial to have longer tests, as the temperature gradient did vary slightly with time.
An additional area that I would have been interested in exploring was ice pack composition. Given our interest in cooler inserts to look at how changes in the ice geometry over time affect the uniformity, it would also have been interesting to look at how changing the composition of the icepack (e.g. adding salt, or starch, could affect the freezing point and therefore state of the icepack. However, our partner was very keen to only have water in the icepack to make it as fail-proof and easily manufacturable as possible, so given this and the limited time, it was not an avenue we decided to explore. 

## Conclusion
This project investigated potential causes of the temperature asymmetry observed within the SMILE Go vaccine cooler, where the top compartments remained warmer than the bottom ones. We designed a built a temperature monitoring system and then conducted a series of thermal tests on the cooler, investigating convection, potential hotspot areas like the door, uneven ice distribution and ice pack contact. 

Our results showed that the temperature gradient formed very quickly, and although we tested several hypotheses, the gradient still persisted. Some of our design changes did lead to slight reductions in the asymmetry, which suggests the gradient may not be caused by a single dominant mechanism but rather by multiple contributing factors. The door was found not to be a significant cause of the gradient, while the ice pack insert, improved top contact and convection tests showed some slight improvements. The cooler insert showed the most promise, appearing to reduce the difference by up to 2°C. Furthermore, forced air circulation using fans was the only change that reduced the gradient to almost zero. 

Going forward, we recommend conducting further tests to validate and further expand on our findings. Experiments should be repeated to identify any anomalies and ideally, should be conducted in a controlled environment. Additionally, it would be valuable to investigate whether the temperature within a vaccine vial (in a compartment) is the same as the measured compartment temperature.

Based on our findings, the insulation of the cooler should be improved in order to get the compartments within the acceptable temperature range. This improved insulation may also help reduce the asymmetry. Additionally, active low-power systems such as the fan appear viable and should be considered as a potential solution.

Overall, the project assessed a range of potential causes of the temperature gradient seen across the vaccine carousel, but did not identify a single primary cause. Nevertheless, it has provided valuable initial insight into the problem from which further investigation can be continued.

## AI use statement: AI was used to check for grammatical errors

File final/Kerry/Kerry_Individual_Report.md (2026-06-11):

# Technology For the Poorest Billion - Individual Report
## IDEABATIC – Uniform Cooling Solutions 
## Kerry Dai (with Kavita, Karen and working with Kitty and Oliver) 
## Introduction 
Vaccines are used all over the world to save lives and must be kept within a temperature range of 
2-8C to remain useful. In some areas such as rural Cameroon, it is difficult to maintain the strict 
temperature requirements for the vaccines, and cooler boxes must be used for the last mile of 
the delivery of the vaccines to remote locations. IDEABATIC created the SMILE vaccine cooler 
box, a cooling system designed to keep vaccines cold during transportation. The SMILE Go is a 
prototype designed to be a smaller, lighter, and easier to carry version of the SMILE.  

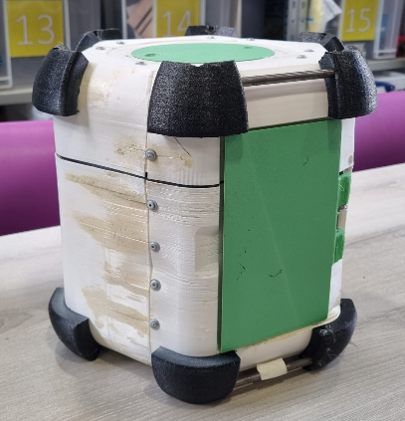
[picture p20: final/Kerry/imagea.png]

 
In previous testing, it was discovered that there is present an asymmetric cooling effect in the 
SMILE Go, where the upper vaccine compartments are warmer than the lower sections. This 
project aims to investigate and explore the reasons why such a temperature differential exists, 
and to offer suggestions as to what possible ways it can be mitigated.

## Technical Progression 
### Direction  
This step in this project involved extensive research and brainstorming into the different ways to 
approach investigating the non-uniform cooling. As a team, it was initially decided that two main 
branches of exploration were the most promising – bottle inserts, which were strongly suggested 
by Oliver and Kitty as an interesting path to conduct research, and convection, which the team 
was interested in looking at. As the project progressed, new information and ideas surfaced, 
changing the testing schedule and allowing the team to diversify what variables were examined. 
For example, noticing that the ice pack did not sit completely flush in the housing gave the team 
inspiration to test the cooler when the ice pack was pressed into the upper surface of the cooler 
rather than letting it sit on the bottom.  

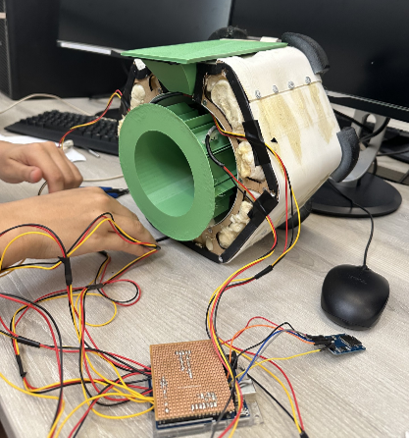
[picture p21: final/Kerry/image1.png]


### Experimental Set-up 
The project involved extensive temperature sensing to navigate the testing. Much credit is due for 
Kavita, who managed to handle the electrical side of this project, soldering temperature sensors 
to the Arduino board and writing the code for the testing.  

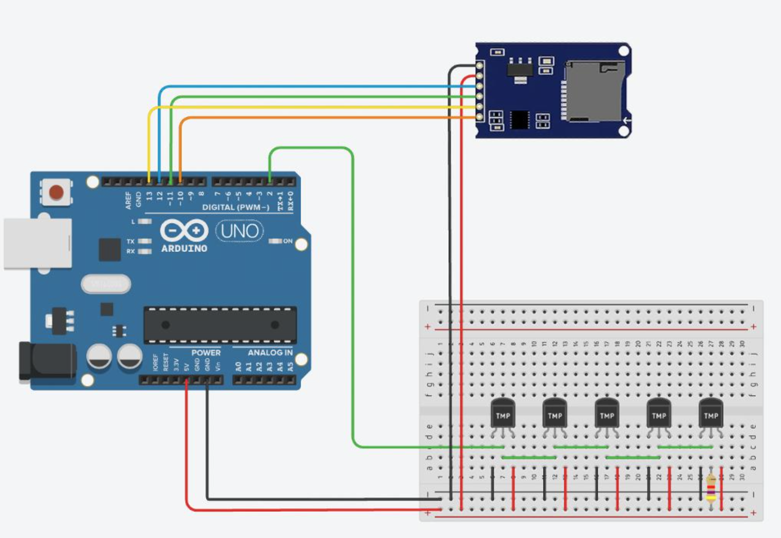
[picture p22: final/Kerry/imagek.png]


*Credit to Kavita for making this electrical diagram.*

Five temperature sensors were used, four of which were placed in the vaccine chamber (two 
upper and two lower) while one was kept outside in the ambient air. Wires were stripped of their 
outer insulation, in order to fit them between the gaps in the cooler box when assembled. The 
Arduino was connected to a PC in the Dyson Centre, which is constantly powered and can keep 
the tests running overnight if needed.  

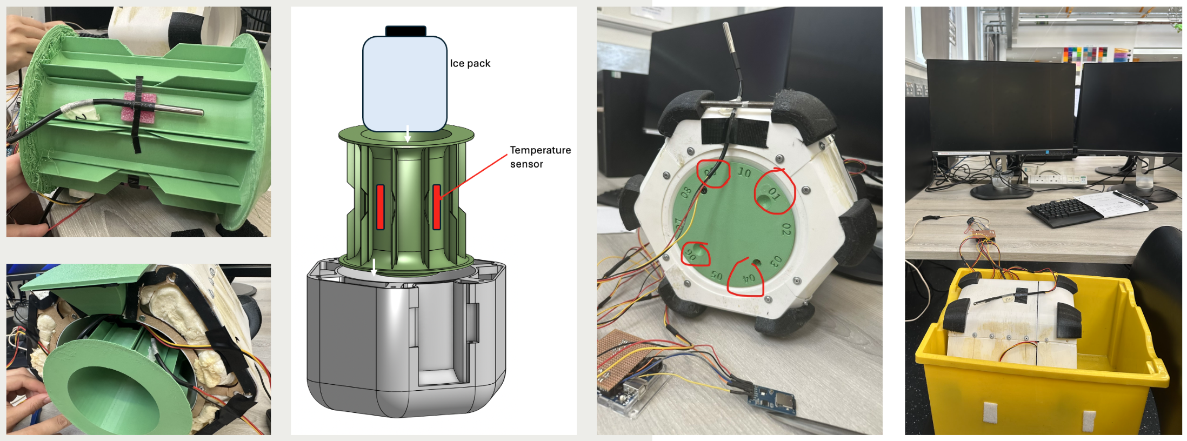
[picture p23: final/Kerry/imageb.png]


*Credit to Kavita for putting this series of images together.*

The vaccine carrier/cooler box was then placed in a waterproof tub, to ensure any faults in the 
set-up which caused water leakage wouldn’t come into contact with the electrical components.

### Testing 
Testing involved many different set-ups: 
- Control Test (no modifications to the original design)
- Bottle Inserts – PLA 3D printed sheets were printed and hot glued inside the bottle to segment the inside of the bottle into four separate, airtight sections. 
- Door Test – The door side of the vaccine carrier was relocated to the bottom side, rather than the top, which was the designed position. 
- Improved Contact Test – The ice pack/bottle was lifted, within its housing, so that better contact was made with the top surface of the housing. 
- Convection Test (Radial Planes) – Card cutouts were pressed into the vaccine chamber spaces.
- Combination Test 1 – Radial planes set-up in addition to improved contact set-up.
- Combination Test 2 – Radial planes set-up, bottle insert added, in addition to improved contact set-up. 

The above tests were intended to be used to narrow down the reasons for the asymmetrical 
cooling and to see how much of the phenomenon was attributed to each factor that the team 
intended to test.

Further tests were conducted with hypotheses surrounding how the asymmetric cooling issue 
could be mitigated. These tests were more solution-oriented and did not necessarily narrow 
down the search space for the source of the non-uniform cooling. 
- Fan Test – Low powered electrical fans inserted into vaccine chamber. Credit to Tom Bashford during the Project Proposal presentation for suggesting this idea.
- Vertical Test – Vaccine carrier oriented in the vertical direction, rather than horizontal.

More detail is given about all the tests and the reasoning behind them in the 
Results and Discussion section of this report. 

### Inserts Research 
To make a complete assessment of the implications of our insert tests, research was conducted 
by Karen and I into the materials properties of PLA and our insert sealing methods. 

The idea behind creating inserts is that the non-uniform cooling could be caused by the non-uniform 
ice, water, and air distribution within the ice pack itself as it melts, since each phase 
has a different density and buoyancy. Thus, by more evenly distributing the phases within the 
bottle, the asymmetry could be mitigated. 

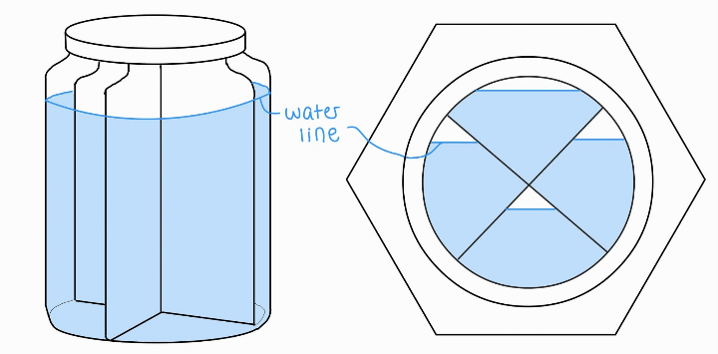
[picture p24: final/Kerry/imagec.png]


*Credit to Karen for making this cooler insert diagram.* 

The cooler inserts were manufactured from 3D-printed PLA due to its low cost, quick 
prototyping ability, and low-cost complexity. While useful for experimental testing, several 
limitations were identified. PLA can become brittle at low temperatures and may degrade over 
time through repeated freeze-thaw cycles and water absorption. The layer-based nature of FDM 
printing also creates microscopic voids, reducing waterproof capacity and airtightness (over 
long time periods). In addition, the hot glue seals used to bond the inserts to the bottle were 
good for short term prototyping but aren’t able to provide reliable long term performance due to 
their structural weakness and delaminating. The Bambu printer produced higher-quality print 
consistency and reduced porosity compared to the cheaper printers at the Dyson Centre. For 
future testing, materials such as PETG could improve waterproofing and low temperature 
durability. Sealants such as epoxy coatings or silicone could provide enhanced waterproofing. 
For large scale production, an easier manufacturing approach such as blow moulding would be 
used, as it would eliminate manually sealed joints and create a more durable, airtight and 
watertight bottle for the vaccine cooler. 

### Gluing Inserts 
As part of the insert tests, a watertight and airtight seal was required between the interface of the 
PLA inserts and HDPE bottle/ice pack. The team delegated this part of the work to me.  



Prior to any testing being done, while the electronics were being put together by Kavita, a sample 
insert was printed (credit to Karen for all 3D printing). This was used by me to trial a hot gluing 
sample. It was a very important step in the insert testing process as it allowed the team to get a 
better grasp on the process which would take much time during the length of the project, over 
two separate tests.  

For possible future prototype testing and for handover information, listed below are suggestions 
on the hot gluing process. 
- Seals are best made using one continuous hot running pool of glue rather than repeated heat-cool cycles.
- Using probes or tools to move the glue is impractical – it is far too adhesive and will stick to the tool and hinder the formation of a smooth seal. 
- The hot glue gun is too large to enter the spaces that the bottle and insert creates – gravity must be used to direct the glue to the appropriate interfaces.
- Iterative, regular testing should be conducted as the gluing process is occurring, to identify locations of any leaks in the seal. 

The hot glue is an effective sealer for testing purposes as it remained structurally intact after a 
freeze-thaw cycle, while also retaining water/air proofing capabilities throughout the test cycle. 

 

### Convection 
A hypothesis regarding the non-uniform cooling is that it is the natural convection of the air within 
the vaccine chamber that is causing the hot air to rise to the top of the chamber while the cool air 
that is generated at the top of the chamber falls to the bottom. This leads to a temperature 
differential that is reflected in the data collected by Kitty and Oliver in their previous experiments, 
where the chambers near the top of the cooler are warmer than those at the bottom.


 
The convection testing side of the project was directed much by me, especially the research, but 
Karen and Kavita both contributed great input in putting the test together. In general, the testing 
portions of the project were performed very much collaboratively as a team. 

Notice in the data that the non-uniform cooling effect is instantaneous. If the source of the 
problem were related to the ice distribution within the bottle, perhaps it would be expected that 
the temperatures initially start out relatively identical, since the ice has not melted enough to 
have a significantly uneven distribution within the bottle. In this case, once the ice starts to melt, 
it would be expected that the temperatures differentiate as the water-ice-air ratio evens out 
(creates more non-uniformity).  


 
However, consider that it is convection that causes the temperatures to be different. The natural 
convection effect is, on the timescales of the experiment, much faster, as the cooler air generated 
at the top surface convects to the bottom of the chamber quickly. The transient motion of the air 
falling is unlikely to occur on the timescale of hours. Thus, we expect a temperature difference 
between the top and bottom of the chamber as soon as the experiment has started. 

#### Methodology 
Experimentally, there are two ways that were proposed to mitigate the temperature gradient 
caused by natural convection within the vaccine chamber. 

##### Stop the flow (Radial Planes) 
To stop the flow of air around the chamber, add radial planes that stretch from the inner radius of 
the vaccine chamber to the outer radius, and extend from the front to the back end. These planes 
should be as well-fitting as can be reasonably constructed, to best resist the flow of hotter air to 
the top section, and the flow of cooler air to the lower sections. Some air gaps will still exist, 
which will decrease the effectiveness of stopping the convection. 
However, it may be such that the radial planes are effective enough to create more uniform 
cooling.  


 
From research, if taken to a much smaller scale, this is how insulation works. For example, 
fibreglass insulation creates a fine web of fibres, which traps air into very small pockets and 
resists its flowing motion. This convection design essentially makes use of this principle, but on 
a larger scale.  

 
 
The experimental set-up utilised ten thick pieces of card cut into slightly oversized planes, which 
were inserted into existing slots on the vaccine carousel, and taped to ensure better airproofing. 
Being slightly oversized meant that the entire carousel needed to be forced into the vaccine 
chamber, which slightly frayed the ends of the card and applied pressure between the card and 
the PLA – crucially creating something like a moulded seal along the edge of the planes. P-shaped 
foam seals were used at one end of the vaccine carrier where the seal had a large gap. 

###### Radial Plane Effectiveness 
A test was conducted to see how well the radial planes stops cold air from falling into lower 
sections of the chamber. Ice cubes were placed in the very *top* of the vaccine carousel, and 
temperature readings were taken over time to assess the rate at which the lower sensors would 
cool, compared to the sensors nearer the top of the chamber (closer to the ice). This was 
compared to the same experiment, but where no planes are present. The idea is that the 
progression of the cool air from the ice at the top of the vaccine carousel might have more 
difficulty travelling from the upper chamber to the lower section with the planes in place.

A towel was placed in the central section of the box where the ice pack normally sits. This is to 
stop any convection currents in that region from cooling the lower section of the vaccine cooler 
box affecting the results. 


 
After 100 minutes of testing with the radial planes present and the ice at the top of the carousel, 
the bottom two sensors did not show a large temperature drop at all, however the top sensors 
did show a decent drop in temperature. Without the radial planes, the lower sensors did show a 
drop in temperature. This suggests that the planes are effective over some time at stopping the 
cold air generated from the ice from falling quickly to the bottom of the chamber. The 
meaningful quantification of this change requires more extensive testing and analysis, but it 
provided enough information for the team to progress.  



Note that in this case, S3 and S4 are the sensors at the **bottom** whereas S1 and S2 are the sensors at the **top** of the vaccine chamber.

##### Force the flow (Forced Convection) 
By using a small fan, the air within the vaccine chamber can be forcefully convected and kept 
more uniform. This would keep all the positions of the vaccine in air of the same temperature, 
roughly, and eliminate the non-uniform cooling effect, if the temperature difference is truly 
present in the air (rather than, for example a conduction pathway or radiation from the ice pack, 
which is unlikely). 

One caveat to this test is that the fan may cause its own heating from the electrical components 
that run the fan. This effect can be mitigated by running the fan intermittently, which prevents it 
from overheating.  



It is critical to note that this test is more solution-oriented, rather than aiming to identify the 
source of the non-uniform cooling. This is because the fan effectively hides or covers the non-uniform 
cooling’s source by mixing all the air together, regardless of where the cooler/warmer air 
has come from. For example, if the asymmetric cooling effect stems from an uneven ice 
distribution within the ice pack, a forced convection test would still theoretically result in more 
uniform cooling since the air in the vaccine chamber is forced to mix. 

###### Fan Issues 
The Arduino board is not able to handle the current draw of even very small fans, which require 
at least 80 mA of current whereas the Arduino itself can supply only a maximum of 40 mA. An 
external power supply would be required to power the fans, possibly connected to a relay which 
is then controlled by the Arduino. This would mean that the fan can be kept running 
intermittently to avoid heating the vaccine chamber from the fan’s electrical components.  

However, looking into the case where the use of a fan might be considered in the field, the fact 
that it has a requirement of a power supply beyond that of the Arduino increases the electrical 
complexity and thus cost of manufacture of the SMILE Go. Perhaps with the addition of further 
electrical functionality for the SMILE product, such as the temperature predictor and monitor 
display project by a 2024 team, a fan could be integrated easily. However, for the purposes of 
this project, the electronic complexity of this system is slightly beyond the scope, with the main 
focus being using our existing capabilities to investigate the non-uniformity of the cooling to the 
best of the team’s ability. 



An alternate solution that was considered is using a USB-powered fan for the convection test. In 
this case, the fan would be completely isolated from the Arduino and temperature sensor 
circuit, drawing power from a USB port elsewhere. USB ports cannot generally be controlled to 
be turned on or off, so the fan would be running continuously - likely generating heat and 
affecting the cool-life of the vaccines. However, the heat generated would theoretically be 
distributed evenly throughout the vaccine chamber due to the forced convection from the fan. 
This allows the project to still investigate the relative temperatures of the vaccine holder 
locations and assess the uniformity of the cooling. This ultimately was the experimental set-up 
used.  

### Results and Discussion 
The results showed some promising results despite a few uncontrollable factors that were 
present during the testing phase of the project. This includes the ambient temperature – the first 
control test result was taken in an environment exceeding 25C, but following tests showed 
ambient readings nearer 20C. Thus, a second control test was conducted at around 20C for better 
comparisons.  

For specific test results and analysis, please refer to the **Test_Results_and_Analysis** document attached in 
the Git repository (in the "final" folder - 2026-Ideabatic/final/Test_results_and_analysis.md). 

To note some interesting observations made from the **Test_Results_and_Analysis** document: 
- For most tests, the temperatures within the vaccine carrier seemed to plateau to a consistent value after a few hours (5-7) once the initial transient cooling dip passed. This is why some tests were run for shorter periods of time (as well as giving the team much needed time to run further tests). It is noted that the ice pack was frozen in the materials laboratory freezer in the Engineering Department, for which the temperature is not known – thus, the initial transient effects that cause the sensors to dip to a very cool temperature may be attributed to the ice pack being colder than in Kitty’s testing.
- The fan test effectively eliminated non-uniform cooling within the vaccine carrier. The data collected acts as a proof of concept for a solution which would mitigate the asymmetry investigated in this project.
- A number of tests on individual factors resulted in small improvements of temperature differences, but the tests which involved a combination of factors, such as radial planes as well as improved contact of the ice pack, showed more promising results and smaller temperature differences than observed in other tests. This suggests that the interactions between different factors tested are important to consider and contribute to the non-uniform cooling effect.  

### Further Testing and Possible Design Solutions 
Although the testing in this project provided valuable insights into the causes of non-uniform 
cooling within the SMILE Go, further work is required to validate and expand upon these findings 
to make effective conclusions. Future experiments should be conducted under more tightly 
controlled conditions, with multiple repeat tests and a regulated ambient temperature 
environment to improve the reliability and validity of the results. Longer duration testing across 
the full cooling cycle would help determine whether the observed temperature gradients persist 
over time and whether the changes made per test have an effect in the long run. Additional 
investigations could explore a wider range of ice pack insert geometries, repeat the convection 
experiments with a fully airtight seal, and assess the impact of wear and damage to the cooler, 
particularly around the door where gaps seemed to develop following repeated use and from 
previous year’s drop testing. It would also be valuable to compare chamber air temperatures with 
temperatures measured directly inside vaccine vials, providing a more representative 
assessment of the conditions experienced by the vaccines themselves. Finally, an investigation 
into the insulation and its effect on the cooling phenomenon could be interesting – this is not 
something the team focussed on during this project. For example, does the foam insulation 
porosity play into the cooling behaviour significantly? Will thicker insulation in certain areas 
mitigate the temperature difference better? This is implemented in IDEABATIC’s larger SMILE version.

The results obtained during this project also suggest several potential design improvements. 
Since the current insulation is sometimes insufficient to consistently maintain the required 2–8°C 
temperature range, additional insulation could be included, particularly in the upper sections 
of the carrier where temperatures were higher. Alternative ice pack configurations, such as the 
use of multiple ice packs positioned at different locations within the carrier, may also help 
improve temperature uniformity. Improvements to the fit between the ice pack and its housing 
could reduce air gaps and create more consistent thermal contact. Furthermore, promising 
results were observed when the carrier was oriented vertically and show that a vertical design 
could be considered in future designs if further testing showed promise. Finally, the forced 
convection experiments showed that increased airflow mixing has the potential to almost 
eliminate cooling asymmetry. This makes it a particularly promising direction for future 
development. 

## Conclusion 
This project investigated the sources of non-uniform cooling within the SMILE Go vaccine carrier, 
where the upper vaccine compartments were found to be warmer than the lower compartments. 
Through experimentation, several potential causes were tested, including uneven ice pack 
cooling, natural convection, door heat entry, and improved thermal contact between the ice pack 
and its housing. 

The results confirmed that non-uniform cooling remained present throughout testing, with 
baseline temperature differences of around 5°C between the upper and lower compartments. A 
significant improvement was achieved using a 3D-printed insert designed to redistribute the ice, 
water, and air within the ice pack, reducing the temperature difference by approximately 2°C. In 
contrast, the door orientation, convection, and improved-contact tests produced only minor or 
no improvements when performed independently. However, combining multiple modifications 
resulted in a reduction in temperature difference of about 1.5-2C, suggesting that the asymmetry 
in cooling could be caused by several interacting factors rather than any single mechanism. This 
is something to be looked into further. 

The forced convection experiments produced effectively uniform temperatures throughout the 
vaccine chamber, showing that airflow mixing may provide an effective solution for mitigating the 
temperature difference. This project also emphasises the issues of the overall thermal 
performance of the smaller vaccine carrier, as temperatures occasionally fell below the 
recommended vaccine storage range during the early stages of cooling, and sometimes even 
plateaued to a temperature above 8C. 

Overall, the project identified and evaluated several potential causes of non-uniform cooling, 
suggested promising mitigation strategies, and provided recommendations for future testing and 
design improvements. While a conclusive cause was not identified, the project offers a strong 
foundation for future development of the SMILE Go vaccine carrier. 

The project was supported by strong teamwork and collaboration between all team members. All 
technical decisions were discussed and agreed upon collectively, making sure that different 
perspectives were considered throughout the project. Tasks were delegated efficiently according 
to project needs and individual strengths, so work could progress in parallel while keeping a high 
level of communication and coordination across the team. 

##### References and Accreditation 
❖ ChatGPT was used for grammatical and editorial purposes for this report. 

❖ IDEABATIC Git Repository information was used. 

❖ Previous years’ work on the same project was used.

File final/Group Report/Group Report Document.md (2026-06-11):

# Context and Summary

Vaccines save millions of lives every year, but they must be kept within a strict temperature range of 2–8°C to stay effective. 
Keeping these temperatures can be very difficult in remote regions where access to reliable electricity and refrigeration is limited, 
and current cooler boxes used for transporting vaccines in the last-mile stage from storage warehouses to remote villages have 
several design flaws that lead to potential vaccine spoilage. To address this, IDEABATIC created the SMILE vaccine carrier, a 
passive cooling system designed to keep vaccines cold during transport to hard-to-reach communities. The most recent prototype 
is the SMILE Go, which is a smaller, lighter version of the original, making it easier for healthcare workers to carry vaccines 
during last-mile delivery.



Our project focused on a cooling issue that had been identified within the SMILE Go. Initial testing conducted earlier this 
year revealed a persistent temperature gradient, where vaccines stored in the upper compartments of the vaccine carousel were 
consistently warmer than those in the lower compartments. The causes of this temperature gradient had not yet been investigated 
on the SMILE Go. Reducing this temperature gradient would optimise performance (keep the vaccines within the required temperature 
range for longer) and provide greater confidence that all vaccines are stored under equal conditions. Thus, this project aimed 
to investigate the variables driving this non-uniform cooling.

 



To understand the cause of this behaviour, our team designed and carried out a series of experiments on the current SMILE Go 
prototype. We assembled a temperature-monitoring system and produced several 3D-printed components to measure how temperatures 
changed throughout the vaccine carrier over time. Several possible explanations were investigated. These included uneven cooling 
within the ice pack, heat entering through the access door, natural movement of air inside the vaccine chamber, and differences 
in how the ice pack contacted its housing.

A baseline test confirmed that the upper compartments could be 6–7°C warmer than the lower compartments. Given that the required 
range of the vaccines is only 6°C, this showed that this cooling non-uniformity was a significant problem. To investigate 
possible explanations, we then modified different aspects of the carrier and compared the results. Some changes, such as altering 
the orientation of the carrier to investigate heat entering through the door, produced very little improvement. Similarly, 
changing the way the ice pack contacted its housing had little effect when tested on its own. More promising results were achieved 
with modifications designed to alter the cooling distribution within the carrier. A 
redesigned insert placed inside the ice pack reduced the temperature difference by approximately 2°C. In addition, the radial 
planes test, which resists natural convection, showed a 1°C improvement. Two separate tests combining modified convection airflow 
pathways with a modified ice pack position (contacting the upper surface of its housing rather than the bottom) and one with 
a cooler insert achieved a similar improvement, suggesting that the non-uniform cooling may be caused by several factors interacting 
rather than a single dominant issue.

Finally, we investigated whether actively moving air inside the carrier could improve temperature uniformity. Using small, 
low-power fans, we found that temperatures became almost identical throughout the vaccine chamber. While this approach may not 
be practical in its current form (due to it requiring electrical power), it demonstrates that improved airflow management could 
provide an effective solution in future designs.



Overall, the project narrowed down the most likely causes of non-uniform cooling. The team developed and tested potential 
improvements and provided IDEABATIC with valuable data to support the development of more effective vaccine delivery systems.

# Sustainable Development Goals and UNICEF Principles for Digital Development 

The SMILE Go project aimed to investigate non-uniform cooling within a vaccine carrier designed to support vaccine delivery 
in remote and low-resource communities. By improving our understanding of the factors causing this asymmetrical cooling, the 
project contributes to the improvement of vaccine storage and transport for these populations. As a result, the project aligns 
with several UN Sustainable Development Goals (SDGs), particularly SDG 3 (Good Health and Well-Being), SDG 10 (Reduced 
Inequalities), SDG 9 (Industry, Innovation and Infrastructure), and SDG 12 (Responsible Consumption and Production).



## SDG 3 – Good Health and Well-Being

The primary objective of the project directly supports SDG 3 by contributing to the safe storage and transportation of vaccines. 
The non-uniform cooling observed within the current SMILE Go cooler could expose some vaccine compartments to temperatures outside 
the recommended storage range, reducing vaccine efficacy. If the temperatures go below zero, the vaccines may freeze and, above 
8°C, can experience breakdown. Through our investigation, the performance can be improved to help ensure that vaccines remain 
effective when delivered to healthcare providers and patients, ultimately supporting public health outcomes and disease prevention.

## SDG 10 – Reduced Inequalities

Access to reliable healthcare infrastructure is often most challenging in remote regions. Transporting vaccines and keeping 
vaccines in the right temperature range remain significant barriers to immunisation in many parts of the world. The SMILE Go 
cooler is intended to provide an accessible solution for vaccine transport in such environments. By improving our understanding 
of the causes of non-uniform cooling, the project provides data to support future design improvements, helping to make vaccine 
storage more reliable, reduce vaccine wastage, and improve access to healthcare for communities that need it most. Improving 
vaccine preservation can help improve the availability of life-saving immunisations for communities, contributing to more equal 
healthcare.

## SDG 9 – Industry, Innovation and Infrastructure

The project used experimental testing to investigate a practical challenge in vaccine transportation. Temperature sensors, data 
logging, and prototyping were used to assess potential causes of non-uniform cooling, including door leakage, ice pack geometry, 
thermal contact, and convection within the vaccine chamber. The use of 3D printing and low-cost electronics enabled potential design 
improvements which could be tested rapidly and at a low cost. The findings identified opportunities for future improvements in the 
cooler design, manufacturing methods, and material selection, contributing to the development of more reliable vaccine transport methods.

## SDG 12 – Responsible Consumption and Production

Vaccines that are exposed to unsuitable temperatures may lose effectiveness and need to be discarded, resulting in wasted resources. 
The project contributes to reducing vaccine wastage and improving the efficiency of vaccine distribution. The project also considered 
material selection and manufacturing methods, highlighting opportunities for more durable and practical designs in future iterations. 
These were also looked at in the context of accessible materials in these areas such as Cameroon. These outcomes support SDG 12 by 
promoting more efficient use of resources and reducing unnecessary waste within healthcare supply chains.



Although the project was primarily focused on thermal testing, some UNICEF Principles for Digital Development were reflected in the 
approach taken. Throughout the project, design decisions and test results were documented and shared within the team, helping to maintain 
continuity and inform future work. This work was conducted in conjunction with our partner Kitty, who has been to Cameroon and provided 
insight into the current challenges faced there. The work completed is uploaded to the public Git repository, keeping the tests open and 
transparent and available for future use. Data collected backs up our conclusions in this project to help inform future design decisions.

# Project Management

The project was managed using a collaborative approach that balanced team decision making with delegating individual responsibility. 
As a team of three, we aimed to distribute tasks as evenly as possible so that each member could contribute meaningfully to the project 
while developing their own technical skills. Big decisions, such as project planning, interpreting results, and choosing which ideas to 
test and their resulting design modifications, were typically made as a group. However, individual team members took ownership of specific 
tasks, such as conducting research, preparing experiments, analysing data, and developing electronics. This approach allowed us to benefit 
from the skills and perspectives of the entire team whilst still keeping clear accountability for individual tasks.



One important aspect of the project for our team was communication. Initially, many discussions took place through a group chat, which was 
helpful for sharing updates and arranging meetings. However, as the project became more technically advanced, it became increasingly 
difficult to communicate ideas, diagrams, and experimental observations through text messages alone. Misunderstandings occasionally arose, 
and technical discussions could become confusing. To address this, we began holding regular face-to-face meetings in the Dyson Centre on a 
near-daily basis. This was convenient during our testing period as the tests often required team members to be present. These meetings 
enabled faster decision-making and provided opportunities to work collaboratively on problems. Looking back, we would recommend scheduling 
regular face-to-face meetings earlier in similar projects, rather than relying on online communication.



Another key factor which helped us effectively run our project was the use of shared documentation. Early in the project, we recognised 
that experimental data, meeting notes, and presentations needed to be accessible to all team members. A shared Google Drive was therefore 
adopted as the central location for storing project information. This ensured that documents could be easily accessed, edited, or reviewed 
by the entire team. The shared repository also reduced the risk of version-control issues that may be present on Git and prevented important 
information from becoming isolated on individual devices. Additionally, all team members were more comfortable working with Google Drive than 
GitHub. Having organised documentation proved helpful during the report-writing stage, when experimental results needed to be reviewed.



The project also highlighted the importance of adaptability. Experimental work did not progress exactly as initially outlined in our Gantt 
chart due to factors such as equipment availability, long freezing times, and unexpected test outcomes. As a team we constantly adjusted 
our schedule and modified test plans where necessary. Additionally, throughout the testing process, we continuously refined our approach by 
identifying additional potential causes and running further tests to investigate them. This flexibility allowed progress to continue despite 
practical constraints and helped ensure that project objectives were still met.

Overall, the project ran smoothly due to our combination of shared decision making, clear task ownership, regular communication, and effective 
document management. For teams undertaking similar experimental projects in the future, we would recommend holding regular face-to-face meetings, 
creating a shared space for documentation, and maintaining flexible plans. We found these practices improved our collaboration and made it easier 
to respond to unexpected developments.

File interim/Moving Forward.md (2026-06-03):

# Future Work and Next Steps

The testing conducted so far has provided some insights into the causes of non-uniform cooling within the SMILE Go vaccine carrier. One of the most significant observations was the large temperature difference that develops during the first ten minutes of cooling, suggesting that the initial cooling phase could play a key role in creating temperature differences within the carousel. The results also largely ruled out door leakage as a major contributor to non-uniform cooling. Additionally, testing of the inserts with ice segmentation showed some slight improvements in cooling uniformity, indicating that changing the distribution of the ice pack may have an effect on temperature distribution within the carrier. However, a definitive root cause of the non-uniform cooling has not yet been determined, and more investigation is required. Testing also showed that improved insulation may be needed to ensure vaccines remain within the required temperature range throughout the cooling cycle.

## Further Testing

The next phase of the project will focus on experimental testing to investigate the remaining potential causes of non-uniform cooling. A key priority is the convection tests, which will involve introducing forced airflow using a fan to observe the influence of removing natural convection currents within the bottle. If convection is found to have an impact on temperature distribution, future design changes can be developed to mitigate this effect. Further experiments will investigate the effect of the ice pack making contact with only the lower section of the carousel, as this may create uneven heat transfer that contributes to temperature variation between vaccine locations.

## Analysis of Results

Following the completion of further testing, the data collected will be analysed to determine whether any observed changes are significant. This analysis will help determine a better understanding of the reasons for non-uniform cooling.

## Design Improvements

The outcomes of this testing will suggest future design improvements for the vaccine carrier. Once the main causes of non-uniform cooling have been identified, possible solutions can be suggested and evaluated. These could include changes to the carousel geometry, improvements to insulation, redesign of the ice pack arrangement, or the introduction of features intended to reduce temperature gradients within the system. The overall aim of further work is to improve cooling uniformity and ensure that all vaccine positions remain within the required storage temperature range throughout operation.

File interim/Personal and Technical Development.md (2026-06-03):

### Personal Technical Development
Our team works well together and collaborates extensively in most sections of the project, for example when making decisions and discussing project direction, as well as during technical work. Below outlines a general frameowrk for each team meambers' individual technical and personal development throughout the first stage of this project.

**Kerry**
- Developed strong attention to detail through the sealing process, recognising that achieving a reliable watertight seal often required multiple attempts and refinements.
- Learned the importance of iteration and persistence when solving practical engineering challenges.
- Improved communication skills through regular engagement with technicians and technical experts.

**Kavita**
- Strengthened Arduino programming and debugging skills, particularly when troubleshooting COM port and connectivity issues.
- Developed practical soldering skills through the assembly and modification of electronic components.
- Improved time management and adaptability in response to project delays and evolving priorities.

**Karen**
- Gained practical experience with 3D printing, including understanding the effects of porosity, print settings, and material selection on final part performance.
- Enhanced iterative design skills through repeated prototyping and refinement of cooler inserts.
- Developed stronger time management skills while coordinating design, manufacturing, and testing activities.

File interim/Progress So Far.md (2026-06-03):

# Progress So Far - Interim presentation

At roughly the halfway point through the project, a substantial amount of work has been completed. This includes:
* Completing Risk Assessments
* Managing Team Coordination - location, timing, availability, communication, documentation access
* Acquiring sensors, putting together electronics and assembling code for temperature sensing
* Preliminary sensor tests over extended time periods before control test
* Finalised experimental setup and apparatus
* Research and documentation
  * PLA properties, manufacture and suitability in context - e.g. performance limitations of porosity
  * Convection methods and experimental setup
  * Image documentation - design choices noted visually
* 3D printing and iterating bottle inserts for insert tests
* Hot gluing inserts into bottle to create airtight seals
* Completing test of seal/insert integrity over a freeze-thaw cycle and removal methods
* Tests Performed:
  * Control Test
  * Insert Test (1)
  * Door-side-down Test
  * Lifted Bottle Test
* Generating conclusions and further ideas to investigate based on the results obtained

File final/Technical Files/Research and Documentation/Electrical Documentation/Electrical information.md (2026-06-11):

# Electrical Documentation

For this project, we are conducting significant thermal testing, so figuring out the test equipment and method is an important step.

## Previous thermal tests:
Last year’s (2025) Ideabatic group only conducted a single thermal test to check their calculated dimensions/new prototype did in fact stay within the correct range for ~24hrs. This test was conducted on their first prototype (i.e. not the SMILE GO we are now using) and just used a single DHT22 temperature sensor.

In March, Kitty conducted a thermal test on the current SMILE GO prototype (what we used) in a temperature chamber. She used bluetooth tempo disc sensors and placed 2 in the upper vaccine chambers and 2 in the lower vaccine chambers, with one outside to measure the ambient temperature. Note that the temperature chamber did not work successfully and led to a large variation in ambient temperature.

## Our test setup:
Our test setup aims to be similar to Kitty’s: We are placing 2 temperature sensors in upper vaccine chambers and 2 in bottom ones, with one measuring the ambient temperature

The system needs to: measure the temperatures at multiple locations in the carousel, timestamp the data, store the data and allow the frequency of measurements taken to be adjusted.

Temperature sensor: We initially hoped to use the same BlueMaestro sensors as they were wireless and had a resolution of 0.1 degrees. Unfortunately, Kitty was unable to find them. So we looked at alternative options. We assessed cost, necessary accuracy, availability, shape, and the required circuit. After assessing different options, we settled on DS18B20 temperature sensors. These have an accuracy of 0.5°C, work in a range of -55°C to 125°C and multiple sensors can be connected to one Arduino pin because they use different addresses.

| Sensor | Accuracy (°C) | Cost (per unit) | Source | Other Details |
| --- | --- | --- | --- | --- |
| DHT11 | ±2.0 | £7.12 | RS | Minimum temperature of 0°C |
| DHT22 | ±0.5 | £7.25 | Amazon only | Larger temperature range; 2-second readout delay |
| DS18B20 | ±0.5 | £6.22 | RS | Single data wire allows daisy-chaining; only one Arduino pin required |
| RTD Pt100 | ~±0.15 | £38.48 | RS | Higher accuracy and more features than required for this application  |
| Tempo Disc Blue (BlueMaestro) | ±0.3 | £30.99 | Amazon | Large temperature range; Bluetooth connectivity (no wires required) |
| Tempo Disc Red (BlueMaestro)  | ±0.3 | £33.99 | Amazon | Bluetooth connectivity (no wires required) |

_Table of possible Sensors to use_

The setup involved 5x Ds18B20 temperature sensors with their wires going to GND, 5v & pin 2, where pin 2 was connected to 5v via a 4.7k pullup resistor. An SD card module was also connected to the arduino. The arduino was then powered by a computer which also displayed the temperatures in serial monitor as well as writing it to the SD card

| Supplies | Quantity | Source |
| --- | --- | --- |
| DS18B20 Temperature Sensors  | 5 (6 purchased) | RS Components |
| Breadboard | 1 | CUED |
| Arduino Uno | 1 | CUED |
| SD Card Module | 1 | CUED |
| 4.7 kΩ Resistor | 1 | CUED |
| RTC (Real-Time Clock) Module | 1 | RS Components |

_Table of components used/purchased_

| Component Pin | Arduino Pin |
| --- | --- |
| SD Card Module: CS | 10 |
| SD Card Module: SCK  | 13 |
| SD Card Module: MOSI | 11 |
| SD Card Module: MISO | 12 |
| SD Card Module: VCC  | 5V |
| SD Card Module: GND  | GND |
| DS18B20 Sensor: VCC  | 5V |
| DS18B20 Sensor: GND  | GND |
| DS18B20 Sensor: DATA | 2 (all sensors daisy-chained together with a 4.7 kΩ pull-up resistor) |

_Table of arduino pin connections_



The components were initially connected to a breadboard, and tested with the code individually. After ascertaining that all the components (sensors, SD card module) were working, the circuit was soldered to a stripboard using headers to attach it to the arduino. The code was then successfully implemented. 



_Initial Bread board setup_



_Soldered circuit_

We conducted a test equipment experiment to run overnight to check the equipment worked over several hours and to make sure the dyson PC would provide power overnight.

We then ran a control test aiming to get the same results Kitty did, showing significant asymmetry between the top and bottom of the cooler. This allowed us to compare our subsequent test results with this control test to assess the impact our modifications had. 

## Equipment test setup

 

# General test setup
- 4 DS18B20 temperature sensors arranged in the vaccine chambers
- In most tests, positioned such that 2 are in top compartments ( not the very top) and 2 in bottom compartments
- Sensors are positioned such that they are all roughly at the same position in each chamber and roughly the same distance from the wall in contact with the icepack
- Sensors are resting on foam and then taped to remain in position
- Their wires had the outer insulation stripped so that the wires can easily exit the SMILE Go through the edges , without significantly disrupting the seal
- A 5th sensor is attached to the cooler such that it measures the ambient temperature
- All sensors and an SD card module are soldered to a board connected to an arduino
- The arduino is powered by a PC so that data can read in real time on the serial monitor and is stored as a txt file on the SD card
- Once the temperature sensors are attached and it's checked that they are all reading correctly, the vaccine carousel is placed into the cooler, and the end lid screwed on. The icepack is then added and that lid screwed on.
- Cooler is orientated horizontally such that icepack lies horizontal and door is on the top face
- Cooler then placed in a tray for safety - in case of leakage, shouldn’t be near PC
- Backup power supply: in event of PC not being available, add RTC module and 6xAA battery connector to barrel jack to arduino

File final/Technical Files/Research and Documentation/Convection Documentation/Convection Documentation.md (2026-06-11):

General documentation - a more refined description can be found in Kerry's individual report.

# Investigating Convection
A hypothesis regarding the non-uniform cooling is that it is the natural convection of the air within the vaccine chamber that is causing the hot air to rise to the top of the chamber while the cool air that is generated at the top of the chamber falls to the bottom. This leads to a temperature differential that is reflected in the data collected by Kitty and Oliver in their previous experiments, where the chambers near the top of the cooler are warmer than those at the bottom.



Notice in the data that the non-uniform cooling effect is instantaneous. If the source of the problem were related to the ice distribution within the bottle, perhaps it would be expected that the temperatures initially start out relatively identical, since the ice has not melted enough to have a significantly uneven distribution within the bottle. In this case, once the ice starts to melt, we’d expect the temperatures to differentiate as the water-ice-air ratio evens out (creates more non-uniformity).

However, consider that it is convection that causes the temperatures to be different. The natural convection effect is, on the timescales of the experiment, much faster, as the cooler air generated at the top surface convects to the bottom of the chamber quickly. The transient motion of the air falling is unlikely to occur on the timescale of hours. Thus, we expect a temperature difference between the top and bottom of the chamber as soon as the experiment has started.



# Method
Experimentally, there are two possible ways to mitigate the temperature gradient caused by natural convection within the vaccine chamber.

## 1. Stop the flow
To stop the flow of air around the chamber, add radial planes that stretch from the inner radius of the vaccine chamber to the outer radius, and extend from the front to the back end. These planes should be as well fitting as can be reasonably constructed, to best resist the flow of hotter air to the top section, and the flow of cooler air to the lower sections. 

Some air gaps will still exist, which will decrease the effectiveness of stopping the convection. However, it may be such that the radial planes are effective enough to create more uniform cooling - something that can be quantified in the test results. 



From research, if taken to a much smaller scale, this is how insulation works. For example, fibreglass insulation creates a fine web of fibres, which traps air into very small pockets and resists its flowing motion. This convection design essentially makes use of this principle, but on a larger scale. 

## 2. Force the flow
By using a small fan, the air within the vaccine chamber can be forcefully convected and kept more uniform. This would keep all the locations of the vaccine in the same temperature of air, roughly, and eliminate the non-uniform cooling effect, if the temperature difference is truly present in the air (rather than for example a conduction pathway or radiation from the ice pack).

One caveat to this test is that the fan may cause its own heating from the electrical components that run the fan. This effect can be mitigated by running the fan intermittently, which prevents it from overheating. 



It is critical to note that this test is more solution-oriented than aiming to identify the source of the non-uniform cooling. This is because the fan effectively hides or covers the non-uniform cooling’s source by mixing all the air together, regardless of where the cooler/warmer air has come from. For example, if the asymmetric cooling effect stems from an uneven ice distribution within the ice pack, a forced convection test would still theoretically result in more uniform cooling since the air in the vaccine chamber is forced to mix.
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

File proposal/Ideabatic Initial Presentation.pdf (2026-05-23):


# IDEABATIC

# SMILE GO Project

# Uniform cooling solutions

## Kerry, Karen & Kavita

# Problem Overview


Reference: https://www.unicef.org/supply/vaccine-carriers

# Problem Overview

Problem: Asymmetric cooling
- Warmer vaccines at the top, cooler vaccines at the bottom
- Conduction & Convection

Current prototype of SMILE GO:
- Sized down SMILE


- No asymmetric cooling mitigation in the bottle
- Foam spray insulation

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

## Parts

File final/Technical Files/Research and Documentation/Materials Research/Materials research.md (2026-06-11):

# Material research for the insert test

## Prototype material and manufacturing choice:

The inserts tested in this experiment were 3D printed from standard PLA filament. 3D Printed PLA was the simplest and most straightforward choice for the manufacture of the cooler inserts for our testing purposes, being cheap, quick to use with complex geometries, and widely available for the experiment in the Dyson Centre. It is also resistant to warping under reduced temperatures, including that below 0℃. Hot glue was used to create airtight seals at the joining locations for the PLA and the bottle. This was the most suitable option for rapid prototyping as the glue dried quickly and was able to be removed relatively easily.

## Performance limitations:

It is noted that the 3D printed PLA becomes brittle at low temperatures, which may lead to cracking or fracturing under load. In the ideal case, the cooler insert should not be under load very much, since it simply segregates the sections of the bottle. However, if too much water is poured into the cooler bottle and frozen, it may expand excessively and create stresses in the bottle and the cooler insert, leading to failure of the part. In addition, repeated freezing and thawing cycles of a 3D printed cooler insert causes cyclic loading that ultimately leads to more likely failure of the component as it is used.

Beyond the temperature characteristics, it is also noted that 3D printed filament often contains microscopic voids and gaps, especially between extrusion lines, which cause the structure to absorb moisture. As a result, no 3D prints are waterproof or airtight, though it is highly water-resistant if printed to a high enough resolution. This phenomenon was observed with our PLA print on the top of the bottle, where after some time, water permeated through the print. The initial component was printed at 90% infill using a lower-precision consumer-grade printer.

PLA itself is an organic polymer that undergoes hydrolytic degradation in water which can be accelerated by high temperatures. This polymer also has a high water uptake, which over time will cause swelling which results in potential sealing issues due to dimensional changes. The water within the PLA will experience expansion and contraction upon freezing and thawing causing mechanical failure by opening the interfaces between the layers or opening cracks. This can also increase the degradation internally and increase the porosity within the structure. For the purposes of prototyping, the uptake is low over a period of a day, so it remains suitable.

Sealing the interfaces also posed significant challenges. Although hot glue is relatively water-resistant, it is not suitable to connect the interfaces for long term use. Hot glue is weak and only weakly bonds to non-porous polymers like polyethylene, which is what the bottle is currently made of. It becomes more brittle when frozen and has been observed to peel off easily from the PLA surface. When the hot glue undergoes repeated freezing and thawing cycles, the adhesive is likely to progressively debond and lose the airtight seal, permitting water and air ingress between the inserts. One practical difficulty encountered during assembly was applying the hot glue within the bottle to join the PLA inserts to the bottle sidewalls, although careful application allowed the interfaces to be sealed sufficiently for prototype testing.

## Material and manufacture improvements:

For a low-scale, portable use, the method of 3D printing should not be changed. However, waterproof and airtight properties can be improved by using other materials. PETG is also a commonly used filament for FDM and is a naturally water-resistant material. This material exhibits lower water absorption than PLA, which is more suitable for this use case. PETG is also less brittle at low temperatures, demonstrating its suitability to this application. (Moreno Nieto et al., 2021) Unfortunately, this material is unavailable in the Dyson Centre to print with.

Absorption rates into the 3D print change depending on the percentage of infill and the presence of internal voids and surface defects. Subsequent prototypes after the initial prototype were produced using a higher quality Bambu Lab printer where the top and bottom densities were 100% and the infill density was 15%. This demonstrated improved print consistency and reduced porosity while still retaining enough flexibility to be able to be inserted into the bottle. The Bambu Lab printers also demonstrate better first layer quality, without the need for a raft. This printer also has better temperature and motion control, allowing for a more consistent finish on each layer without air gaps. Since this print is done inside an enclosed chamber, there is reduced warping during the printing process.

Coating sealant for the PLA such as epoxy can be used to make the print waterproof. Epoxy cures in anywhere from 12 to 24 hours, which for our timescales is excessive and would place pressure on our project timeline. The epoxy would flow under gravity whilst it cures in the bottle. In contrast, the higher viscosity of hot glue allows it to hold its shape relatively well before it solidifies. However, this cannot be used in replacement to the hot glue which bonds the inserts to the bottle walls. One alternative is the use of silicone sealant. Silicone remains flexible at low temperatures and is highly resistant to water ingress, making it well suited to repeated freeze-thaw cycles. The flexibility of the sealant also allows it to accommodate differential thermal expansion between the bottle and insert, reducing the likelihood of seal failure. However, silicone typically requires curing times of 24 hours or more, making it less suitable for rapid prototyping.

## Production scale solutions:

Assuming the workshops in Cameroon have access to 3D printers, these cooler insert designs can be easily created and produced. However, these inserts will not provide a sufficiently durable seal over the intended 10 year service life of the vaccine cooler. The exact lifespan of PLA depends on the conditions. Cold water and ice does not significantly degrade the PLA as much as other factors such as sunlight, chemical exposure, and humidity but will still cause unreliability in the waterproofing and sealing between the chambers. Furthermore, the adhesive interfaces between the inserts and bottle walls represent potential failure points, particularly as repeated thermal cycling may cause debonding and leakage between chambers.

Another consideration for large-scale implementation is the reduction in available ice volume caused by the inserts themselves. Although the inserts occupy a relatively small proportion of the bottle volume, they displace some water that would otherwise freeze and contribute to thermal storage. Future designs should therefore seek to minimise material usage while maintaining sufficient segregation of the air gap.

For the depth that our investigation goes, hot glue is a viable option, but for long-term use, a more sophisticated manufacturing process is needed to create an air tight seal such as the mentioned silicon sealant. If this was produced at a large-scale production, eliminating separate inserts and adhesive joints would significantly improve durability and reliability over the lifetime of the product. extrusion blow moulding or stretch blow moulding the bottle with a certain amount of chambers could be used. This will create better airtight and watertight seals in comparison to the hot glue. 

## References

Moreno Nieto, D. et al. (2021) *Product design by additive manufacturing for water environments: Study of degradation and absorption behavior of PLA and Petg*, MDPI. Available at: https://www.mdpi.com/2073-4360/13/7/1036?type=check_update&version=2 (Accessed: 30 May 2026).

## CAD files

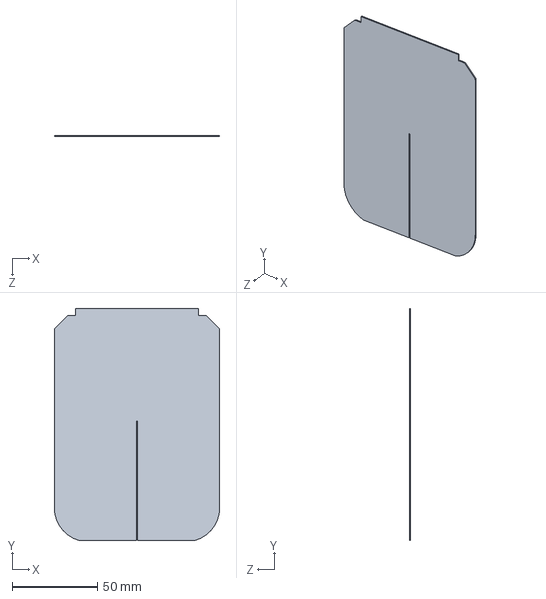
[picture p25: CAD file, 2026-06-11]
final/Technical Files/CAD/Insert 2.SLDPRT
97.0 x 136.0 x 0.8 mm

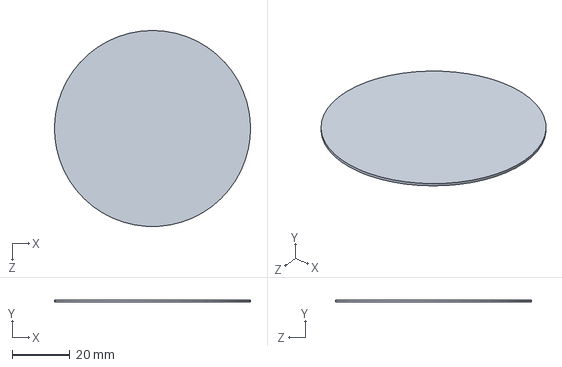
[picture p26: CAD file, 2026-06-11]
final/Technical Files/CAD/Top insert.SLDPRT
68.0 x 0.8 x 68.0 mm

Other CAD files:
final/Technical Files/CAD/Insert 1.SLDPRT

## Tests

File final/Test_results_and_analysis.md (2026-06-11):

**Test Results & Analysis**

**Control test** 

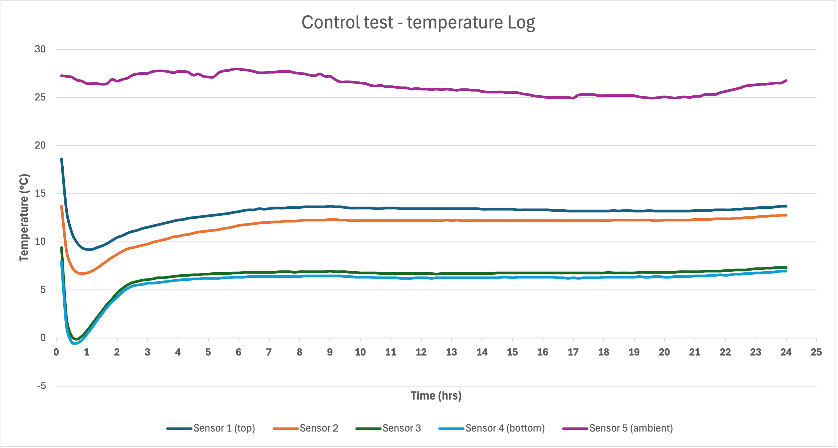
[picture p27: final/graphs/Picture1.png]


Ambient temperature: 25-27°C
Temperature difference (once stabilised): 7°C
Notes: 
Bottom compartments went below 0°C
Once stabilised, top compartment chambers well above required 8°C

**Test setup**

For the control test, the setup was not changed from the general setup. For a more detailed description of the test setup, see the electrical document.

**Test Justification**

To investigate potential causes of the non-uniform cooling, we needed to complete a control test to provide baseline data for comparison with data from following tests where the variables have changed. This allowed us to assess the effects of these variable changes on the temperature gradient. Additionally, we wanted to confirm the results obtained by our partner Kitty, when she conducted a test earlier this year.

**Test Analysis**

This test was conducted at a higher temperature than the initial thermal test our partner carried out earlier this year. As a result, whilst her results had shown the top compartments remaining at roughly 8°C, ours show them remaining at 13-14°C, which is above the required 8°C and therefore suggests the current insulation is insufficient. This is not surprising given that the current SMILE Go prototype has very little sealing at the doors and sides, and because the insulation used was a spray foam which had been distributed very unevenly, leaving plenty of airpockets.
All the temperature sensors show the compartments rapidly cooling when the icepack is placed in before rising again and then plateauing and maintaining a steady temperature for hours, but with the top compartments significantly warmer than the bottom compartments.
As expected, the control test shows the non-uniformity across compartments seen in Kitty’s test, with the top compartments remaining 7°C hotter than the lower ones.
______________________________________________________________

**Door test**
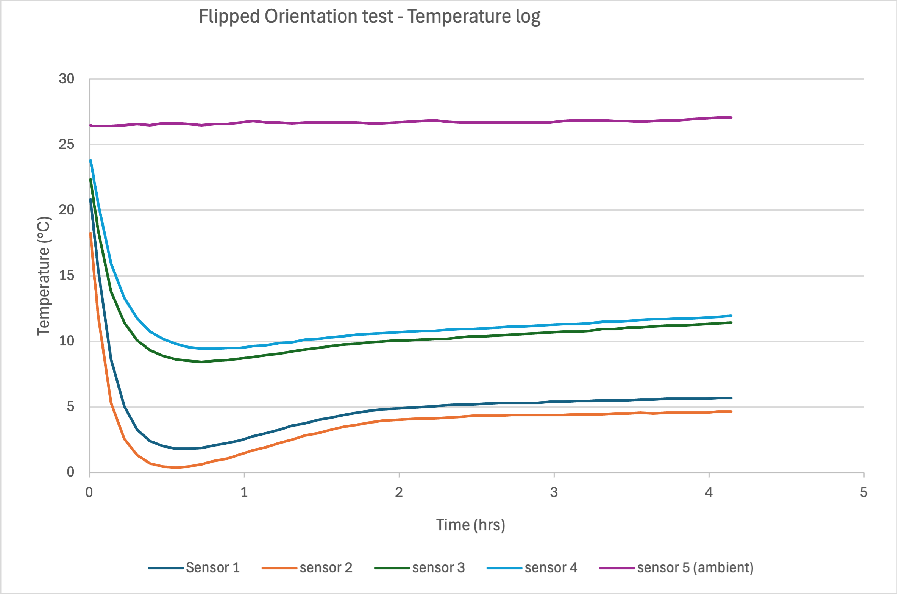
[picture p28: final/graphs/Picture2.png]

Ambient temperature: 26-27°C
Temperature difference: 6-7°C
Notes: 
Bottom compartments did not go below 0°C
Top compartment chambers went well above required 8°C
This test was only run for just over 4hrs

**Test setup**

General test setup used, except the cooler was oriented upside down such that the door was no longer on the top face, but now on the bottom face.

**Test Justification**

One key variable we wanted to test was whether the temperature gradient was caused by heat entering through the door. The door was poorly sealed and had been slightly damaged in previous drop tests. We noticed visible gaps, and because both our control test and our partner’s test were conducted with the door facing upwards at the top, where the higher temperatures were recorded, it was crucial to test the unit upside down. By running a test with the door at the bottom, we could isolate this variable. 

**Test Analysis**

As you can see on the graph, top sensors 3 and 4 still recorded significantly higher temperatures than sensors 1 and 2 which were on the bottom. The temperature difference remained 6-7°C so we were able to rule out the door seal as the dominant cause. Given our tight testing schedule and because it was initially unplanned, we only ran it for 4hrs. However, a more comprehensive test lasting a longer timeframe would be advised.
______________________________________________________________
**Cooler Insert test**
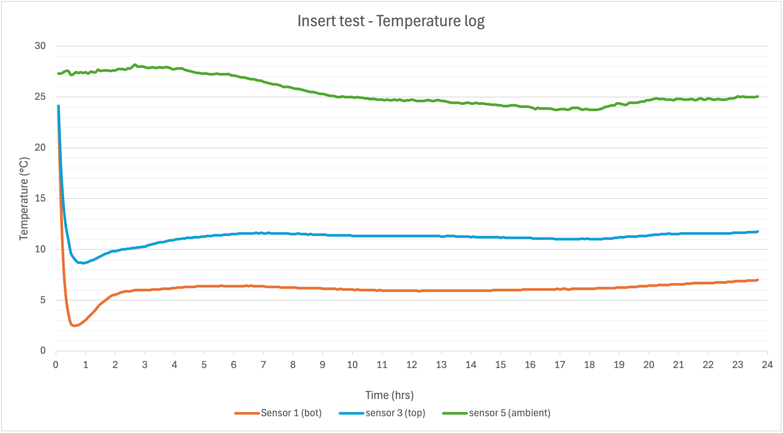
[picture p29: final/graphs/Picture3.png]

Ambient temperature: 24-28°C
Temperature difference: 5°C
Notes: 
2°C improvement in the temperature difference compared to the control
Large fluctuations in the ambient temperature
Potential hole between two chambers

**Test setup**

3D printed inserts in a cross shape with a 3D printed lid glued inside the bottle.

**Test Justification**

This test was performed to see if the large internal air gap in the ice bottle was the cause of the asymmetrical cooling. The inserts segment the ice pack and air pockets reducing the effect of a large air gap.

**Test Analysis**

The 2°C improvement in the temperature difference compared to the control could be attributed to the inserts, however, given the variations in ambient temperature which may have reflected in the results, we cannot conclusively conclude that the inserts were beneficial. Further testing is required to verify the validity of these results. The inserts also do not contribute to the initial temperature drop when the ice is still frozen, but affect the steady-state temperature difference over time.

_________________________________________________________________________
**Top Thermal contact test/Improved Contact Test**
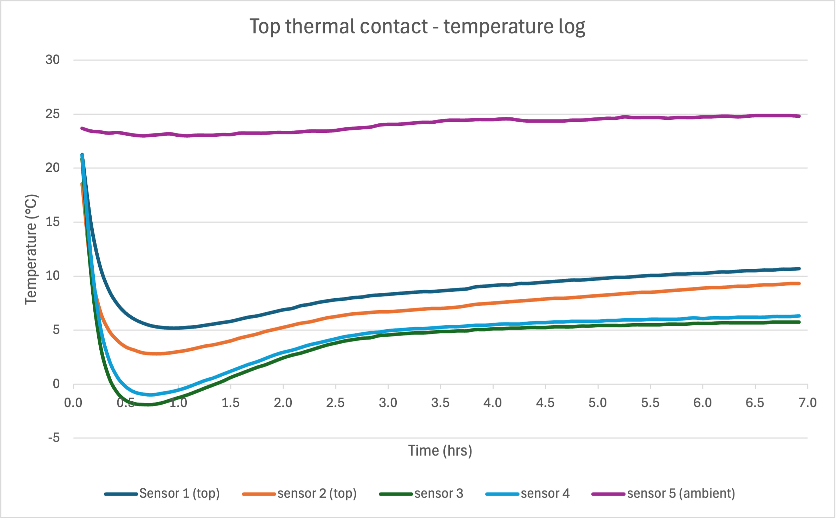
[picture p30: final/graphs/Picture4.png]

Ambient temperature: 23-25°C
Temperature difference: 4.9°C
Notes: 
Contact to top was slightly angled (see test setup below)

**Test setup**
The general test setup was used, but then several additional long,small diameter inserts were mounted to the bottom side within the central chamber where the icepack bottle is placed such that the bottom of the carousel was no longer in direct contact with the ice bottle and the top now was. For this test, this was done with uncooked spaghetti. However, in a later test, thin wooden sticks were used instead as the condensation from the bottle resulted in the spaghetti becoming damp. Additionally, when the bottle was squeezed in, the inserts did shift slightly such that the icepack was raised off the carousel in the bottom right section only.

**Test Justification**
During testing, we observed a tolerance between the cylindrical ice pack and the 3D-printed chamber. Due to gravity, the bottom of the chamber maintained direct contact with the ice pack, while the top had a small gap. Given the temperature gradient we measured and the fact that the bottom of the chamber felt noticeably colder than the top after each test, we investigated whether this uneven contact was contributing to the thermal difference. Furthermore, in between other tests, a quick 20 minute test was conducted with this test setup and it showed potentially promising results; the sensor reading appeared to fluctuate a bit more before starting to show some non-uniformity. Based on this quick test, it seemed appropriate to conduct a longer test.

**Test Analysis**
The results still show a consistent temperature gradient, although it is reduced, suggesting contact could be a contributing factor, but it is not the dominant factor. After 7 hours, the temperature gradient was 4.9°C, compared with 5.5 and 7.0°C in the respective control tests. Given that the ambient temperature in this test fell between those of the controls, a control gradient within that range would be expected.
The icepack being raised off the carousel in the bottom right section rather than the bottom central section, appeared to have little effect on the bottom sensors. However, there was more of a discrepancy between the top sensors. 

_________________________________________________________________________
**Vertical Orientation test**
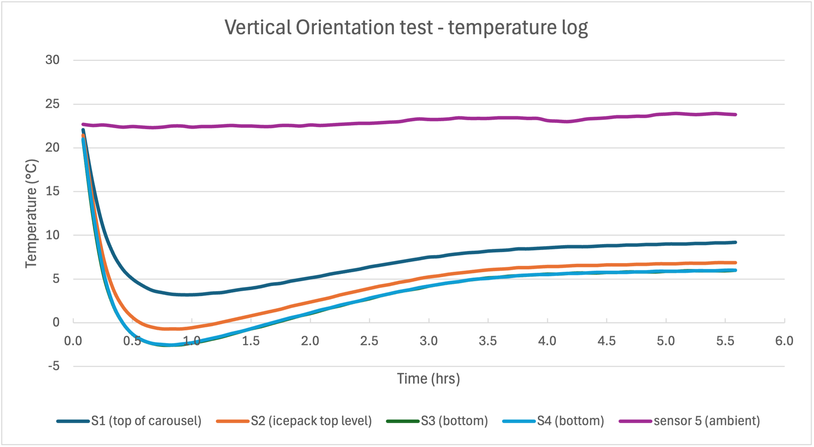
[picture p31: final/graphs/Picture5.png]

Ambient temperature: 22-24°C
Temperature difference: between S2 & S4: 1°C, between S1 & S3: 3.2°C

**Test setup**
The test setup was simply the general test setup, but then oriented such that the cooler was now vertical. We still used 4 sensors inside the cooler, but the sensor positions were changed such that 2 sensors were in each compartment. One measuring at the top and the other at the bottom. In one compartment the top sensor measured the absolute top of the carouse, where the icepack lid was and so no ice in contact with the carousel wall, whereas the other top sensor (S2) was slightly lower such that it was at a level where the icepack was still in contact with the wall. 

**Test Justification**
This was not a test designed to inform us about potential causes of the non-uniformity, but rather a potential solution-based test and an idea we were interested to investigate as our testing had shown us that cold air was accumulating at the bottom in the horizontal orientation, and we wanted to see how that translated/looked like when vertical as the air flow would be different. 

**Test Analysis**
This showed only a 1°C difference between compartment locations at the bottom and top of the icepack (see sensor 2 & 4 in the figure below), which is a considerable reduction. However, this test was only conducted for 5.5hrs and the ice pack does not extend to the top of the carousel, so the temperature measured at the actual top of the carousel (sensor 1) was several degrees warmer. It would be sensible to run a longer test and complete it either with a modified carousel so that the top is aligned with the icepack, or by using a taller icepack.

_________________________________________________________________________

**Convection test**
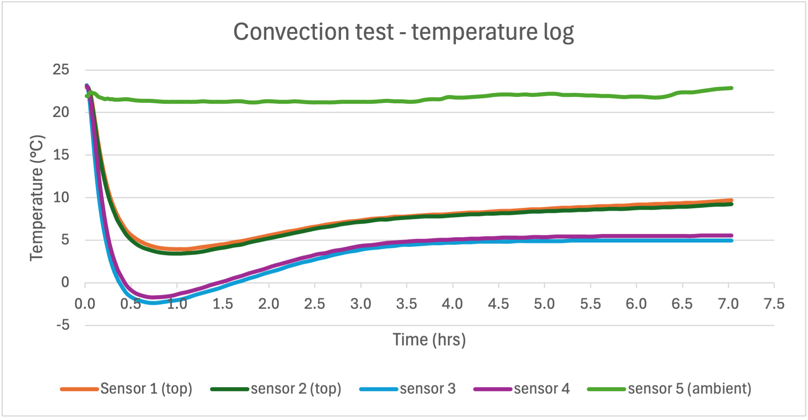
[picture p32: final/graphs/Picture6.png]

Ambient temperature: 22°C
Temperature difference: 4°C
Notes: 
Lower sections dipped below 2C.

**Test setup**

The experimental set-up utilised ten thick pieces of card cut into slightly oversized planes, which were inserted into existing slots on the vaccine carousel, and taped to ensure better airproofing. Being slightly oversized meant that the entire carousel needed to be forced into the vaccine chamber, which slightly frayed the ends of the card and applied pressure between the card and the PLA – crucially creating something like a moulded seal along the edge of the planes. P-shaped foam seals were used at one end of the vaccine carrier where the seal had a large gap. 

**Test Justification**

A hypothesis regarding the non-uniform cooling is that it is the natural convection of the air within the vaccine chamber that is causing the hot air to rise to the top of the chamber while the cool air that is generated at the top of the chamber falls to the bottom. This could explain the temperature difference. 

By inserting radial planes, the air’s natural segregation movement is resisted, and slowed. This may reduce the effect of natural convection in the cooling asymmetry. 

**Test Analysis**

Results show a small decrease in the temperature difference compared to the second control test. A 4C difference is observed compared to the 5C in the control at 6 hours from the start of the test. This is not conclusive evidence that the planes have an effect on the asymmetric cooling, but it is promising. It is to be noted that the radial planes set-up was not perfectly airtight - a further test with an airtight seal could be warranted.

_________________________________________________________________________
**Assessing Convection Setup Effectiveness tests**

*Not* official tests regarding asymmetric cooling!
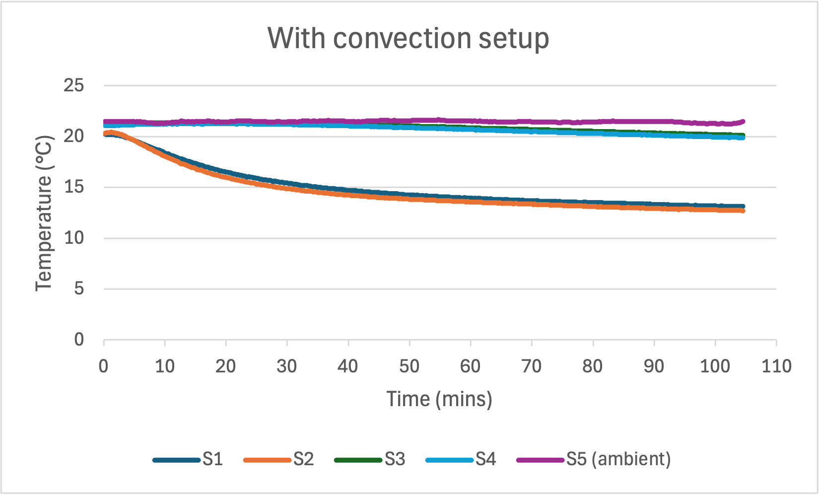
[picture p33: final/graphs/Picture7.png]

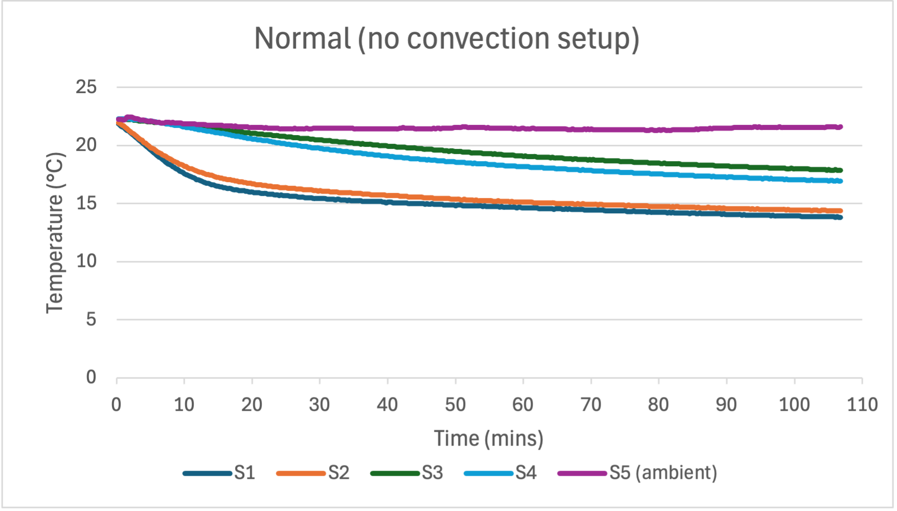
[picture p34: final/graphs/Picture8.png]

Ambient temperature: 22°C
Notes:
Note that in this case, S3 and S4 are the sensors at the bottom whereas S1 and S2 are the sensors at the top of the vaccine chamber.

**Test setup**

Ice cubes were placed in the very top of the vaccine carousel, and temperature readings were taken over time to assess the rate at which the lower sensors would cool, compared to the sensors nearer the top of the chamber (closer to the ice). This was compared to the same experiment, but where no planes are present. 
A towel was placed in the central section of the box where the ice pack normally sits. This is to stop any convection currents in that region from cooling the lower section of the vaccine cooler box affecting the results.

**Test Justification**

This test was conducted to see how well the radial planes stops cold air from falling into lower sections of the chamber. The idea is that the progression of the cool air from the ice at the top of the vaccine carousel might have more difficulty travelling from the upper chamber to the lower section with the planes in place.

**Test Analysis**

After 100 minutes of testing with the radial planes present and the ice at the top of the carousel, the bottom two sensors did not show a large temperature drop at all, however the top sensors did show a decent drop in temperature. Without the radial planes, the lower sensors did show a drop in temperature. This suggests that the planes are effective over some time at stopping the cold air generated from the ice from falling quickly to the bottom of the chamber. The meaningful quantification of this change requires more extensive testing and analysis, but it provided enough information for the team to progress.

_________________________________________________________________________
**Control 2 test (colder ambient temperature)**
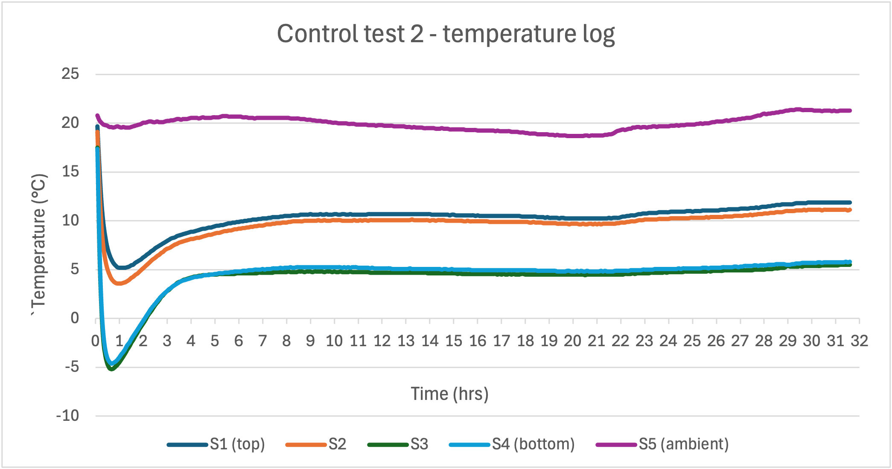
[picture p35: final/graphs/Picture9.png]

Ambient temperature: 18.5 - 21.5°C
Temperature difference: 6°C
Notes: 
This test was run for 30hrs so can start to see temperatures rising

**Test setup**

The setup was the same as the original control (the generic test setup) just at a lower ambient temperature. 

**Test Justification**

In the later weeks of the project, ambient temperatures decreased significantly to 20 degrees. Given we were still conducting new tests and still needed baseline data to compare our test data against, we thought it was important to conduct a second control to compare against as ambient temperature seemed to have a significant effect on the temperatures the compartments stabilised at and therefore potentially the gradient.

**Test Analysis**

As can be seen in the graph, the ambient temperature did affect the temperatures that the compartments stabilised at. They stabilised at significantly lower temperatures than had been seen in the original control test. There was also a slight reduction in the temperature gradient, from 7 in the first control to 6°C in this one.

_________________________________________________________________________

**Convection & contact test (combination)**
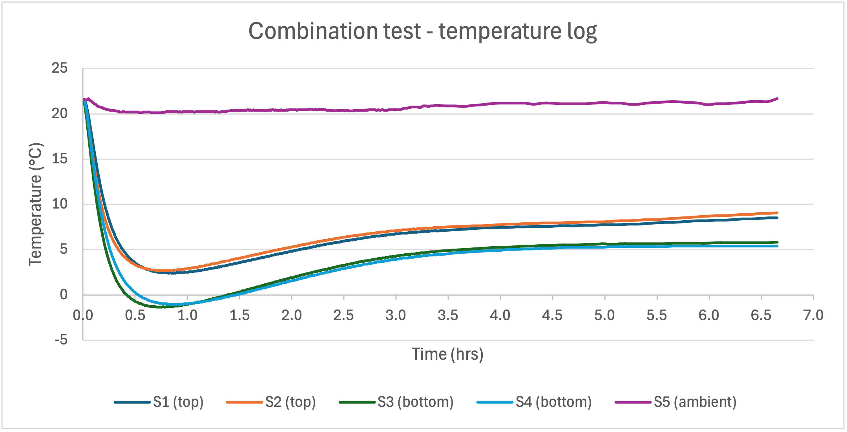
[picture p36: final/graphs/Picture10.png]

Ambient temperature: 21°C
Temperature difference: 3.5°C
Notes: 
Lower section dips below 2C upon cooling
Note that this test was only conducted for 6 hours

**Test setup**

For combination test 1, the ice pack was positioned to improve thermal contact with the upper surface of the housing, and radial planes were simultaneously added within the vaccine chamber to restrict natural convection currents. 

**Test Justification**

Following the testing of individual factors, it was considered valuable to investigate whether combining multiple modifications could produce a greater improvement in cooling uniformity than any single change alone. 

The rationale behind this approach was that improved thermal contact at the top of the ice pack housing would enhance cooling in the upper regions of the vaccine chamber, while the radial planes would help prevent this cooler air from rapidly sinking to the lower compartments. 

**Test Analysis**

The results were promising. Over a six-hour test period, the temperature difference between the upper and lower sections was reduced from approximately 5°C in the control test 2 to around 3.5°C. While neither modification produced an improvement this large when tested independently, the combination resulted in a more noticeable reduction in temperature difference. This suggests that interactions between multiple mechanisms are important.
_________________________________________________________________________

**Convection, contact & insert test (combination 2)**

Ambient temperature: 17.5-21.5°C
Temperature difference: 4°C towards the end at 24 hours, 3°C at 6.5 hours
Notes: 
Test ran for a similar time frame as the control test 2
The graph shows that tests taking ~6 hours are not enough to show the steady-state temperature difference

**Test setup**

As with the test before, the radial planes are put into the carousel to restrict the convection and small inserts are placed beneath the ice pack to prevent contact with the carousel. The 3D printed inserts were hot glued into the ice pack before it was placed into the test set up.

**Test Justification**

We wanted to observe whether a combination of reasons, including the ice pack inserts, could mitigate the effect of asymmetrical cooling. 

**Test Analysis**

Initially, the results look promising with the narrowest temperature range seen at the 6.5 hour mark, however, over time, the upper and lower temperatures still diverge and only result in a 1°C improvement to the control test at the 24 hour mark.

_________________________________________________________________________

**Fan test**

Ambient temperature: 22°C
Temperature difference: small
Notes: 
No initial temperature dip is observed within the first few hours of the test like the other tests

**Test setup**

A solution-oriented experiment conducted during the project was a forced-convection test (fan test). In this test, the air within the vaccine chamber was actively mixed using two small electrically powered USB fans. The fans were powered independently from the temperature sensing system.
 
**Test Justification**

Unlike the previous experiments, this test was not intended to identify the root cause of the non-uniform cooling. This is because forced convection can mitigate many of the possible mechanisms by continuously mixing the air within the vaccine chamber. Whether the temperature asymmetry originates from natural convection, uneven cooling from the ice pack, or another factor, the fan distributes heat more evenly throughout the chamber and “masks” the underlying problem.
Instead, this experiment was used to see whether forced mixing could provide a practical solution to the cooling asymmetry. This system could potentially be utilised in future versions of the SMILE Go if additional electronic systems were introduced to power the fans.

**Test Analysis**

The results were notable, with the temperature difference between compartments effectively gone. All sensors showed very similar temperatures throughout the test, which is a significant improvement compared to other tests investigated during the project.

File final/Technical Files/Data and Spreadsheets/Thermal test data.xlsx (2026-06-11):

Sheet: night - dht22 x1
1 | 28.3 | every 10 mins
2 | 28.2
3 | 27.8
4 | 27.7
5 | 27.7
6 | 27.7
7 | 27.6
8 | 27.6
9 | 27.6
10 | 27.6
11 | 27.6
12 | 27.6
13 | 27.6
14 | 27.5
15 | 27.6
16 | 27.6
17 | 27.5
18 | 27.5
19 | 27.5
20 | 27.6
21 | 27.6
22 | 27.5
23 | 27.6
24 | 27.5
25 | 27.6
26 | 27.6
27 | 27.6
28 | 27.5
29 | 27.5
30 | 27.6
31 | 27.5
32 | 27.5
33 | 27.5
34 | 27.5
35 | 27.6
36 | 27.6
37 | 27.6
38 | 27.6
39 | 27.6
40 | 27.7
41 | 27.7
42 | 27.7
43 | 27.7
44 | 27.7
45 | 27.7
46 | 27.7
47 | 27.8

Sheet: 1st test all 5 ds18B20
1 | 30.87 | 30.25 | 30 | 30 | 30.37
2 | 30.81 | 30.19 | 30 | 30 | 30.37
3 | 30.81 | 30.19 | 30 | 30 | 30.37
4 | 30.75 | 30.19 | 30 | 30 | 30.37
5 | 30.75 | 30.25 | 30 | 30 | 30.37
6 | 30.69 | 30.25 | 30 | 30 | 30.37
7 | 30.69 | 30.25 | 30 | 30.06 | 30.37
8 | 30.69 | 30.19 | 30 | 30 | 30.37
9 | 30.62 | 30.25 | 29.94 | 30 | 30.37
10 | 30.62 | 30.19 | 30 | 30.06 | 30.37
11 | 30.56 | 30.19 | 29.94 | 30 | 30.37
12 | 30.56 | 30.19 | 29.94 | 30 | 30.37
13 | 30.56 | 30.25 | 29.94 | 30 | 30.37
14 | 30.56 | 30.19 | 29.94 | 30 | 30.37
15 | 30.5 | 30.19 | 29.94 | 30 | 30.37
16 | 30.5 | 30.19 | 30 | 30 | 30.37
17 | 30.5 | 30.25 | 29.94 | 30 | 30.37
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

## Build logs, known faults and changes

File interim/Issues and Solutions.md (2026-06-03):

| Issue Encountered | Mitigation |
|---|---|
| Temperature sensors were unavailable at the start of the project, delaying the planned testing schedule. | A contingency plan was implemented by sourcing alternative sensors and adjusting the project timeline. Once testing showed that temperatures stabilised after approximately 5–6 hours, shorter tests could be conducted, allowing progress despite the delay. |
| Only one cooler bottle was available for testing, and replacement bottles were out of stock. | Testing schedules were carefully planned to maximise use of the available bottle. Time was used efficiently between freezing and testing periods to minimise delays and increase the number of experiments conducted. |
| Communication through text messages was sometimes ineffective for discussing technical ideas and project decisions. | The frequency of in-person meetings was increased to improve communication, facilitate faster decision-making, and ensure all team members remained aligned. |
| Early issues were encountered with file storage, version control, and document accessibility across the team. | Google Drive was adopted as a centralised platform for file storage, sharing, and collaboration, improving accessibility and organisation. |
| Hot-glued sensor interfaces did not always produce a reliable watertight seal, leading to the risk of leakage during testing. | An iterative sealing process was adopted, involving repeated application of hot glue followed by seal verification tests. Multiple testing stages were used to confirm seal integrity before experiments were conducted. |
| Initial cooler insert designs did not fit optimally within the bottle, particularly around the threaded neck section. | The inserts were redesigned to better match the bottle geometry and accommodate the lid closure mechanism, improving fitment and allowing the hot-glued interfaces to be sealed more effectively. |

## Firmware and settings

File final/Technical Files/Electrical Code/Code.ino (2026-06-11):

// This is the arduino C++ code used for the temperature monitoring system. Note this does not include code for adding on the RTC module
// Libraries
#include <OneWire.h>
#include <DallasTemperature.h>
#include <SPI.h>
#include <SD.h>

//temp sensor setup
#define ONE_WIRE_BUS 2

OneWire oneWire(ONE_WIRE_BUS);
DallasTemperature sensors(&oneWire);

int deviceCount = 0;
float tempC;

// SD Card Setup
const int chipSelect = 10;
File myFile;

// time signature setup
unsigned long previousMillis = 0;
unsigned long elapsedMinutes = 0;

void setup() {

  Serial.begin(9600);

  // Starting temperature sensor library
  sensors.begin();
  // Finding the connected DS18B20 sensors
  Serial.println("Locating devices...");
  deviceCount = sensors.getDeviceCount();
  Serial.print(deviceCount);
  Serial.println(" device(s).");

  // Initialising SD card
  Serial.print("Initializing SD card...");

  if (!SD.begin(chipSelect)) {
    Serial.println("SD card initialization failed!");
    while (1);
  }
  Serial.println("SD card initialized.");
  // Creating file - name of file changed for each test
  myFile = SD.open("Tempn1.txt", FILE_WRITE);

  if (myFile) {
    myFile.println("Temperature Log");
    myFile.println("----------------------------");
    myFile.close();
    Serial.println("File created.");
  } else {
    // Provides error message on serial monitor, so can monitor SD card setup fails
    Serial.println("Error opening temps.txt");
  }
}

void loop() {
  unsigned long currentMillis = millis();
  // Loop to take reading every x seconds (note number is in miliseconds)
  if (currentMillis-previousMillis >= 600000){
    previousMillis = currentMillis;
    elapsedMinutes++;
 
    // Requesting temperature readings
    sensors.requestTemperatures();

    myFile = SD.open("Tempn1.txt", FILE_WRITE);

    if (myFile) {
      // Reading each sensor
      myFile.print(elapsedMinutes);
      Serial.print("Elapsed time");
      Serial.print(elapsedMinutes);
      for (int i = 0; i < deviceCount; i++) {
        tempC = sensors.getTempCByIndex(i);
        // Printing to Serial Monitor
        Serial.print("Sensor ");
        Serial.print(i + 1);
        Serial.print(": ");
        Serial.print(tempC);
        Serial.print(" °C | ");

        // Writing to SD card
        myFile.print(",");
        myFile.print(tempC);
      }

      myFile.println();
      myFile.close();

      Serial.println("Data saved to SD card.");
      Serial.println();
    }
    else {
      // Provides error message on serial monitor, so can monitor if data stops writing to SD card
      Serial.println("Error opening temps.txt");
    }
  }
}

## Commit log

2026-05-23 test commit 1
    Added details about the problem with the current ice pack design and its impact on vaccine cooling.
2026-06-03 image inserted
2026-06-11 Update Kerry Individual Report
    Added acknowledgments for contributions to the project and clarified the testing process for the cooler inserts.
2026-06-11 labelling lies in image 9
    Emphasize the top and bottom sensor locations in the report and clarify the effect of forced convection.
2026-06-11 CAD files
    [Insert 1.SLDPRT, Insert 2.SLDPRT, Top insert.SLDPRT]
2026-06-11 Create Material research
2026-06-11 cad files folder made
2026-06-11 Rename Material research to Material research.md
2026-06-11 Add insert concepts image
2026-06-11 Create Convection Documentation for Vaccine Chamber
    Added comprehensive documentation on convection effects in vaccine chambers, including hypotheses, methods to mitigate temperature gradients, and testing procedures.
2026-06-11 Create Convection Documentation for vaccine chamber study
    Added comprehensive documentation on convection effects in vaccine chambers, including methods to mitigate temperature gradients and testing results.
2026-06-11 Create materials reaserach folder
2026-06-11 Update and rename README.md to Materials research.md
2026-06-11 Update Materials research.md
2026-06-11 Refine Inserts Research section in report
    Corrected formatting and improved clarity in the Inserts Research section.
2026-06-11 Refine explanation of solution-oriented test approach
    Clarified the explanation of the test's purpose regarding non-uniform cooling and fan effects.
2026-06-11 Update discussion on testing phase ambient temperature
    Clarified wording regarding ambient temperature in results section.
2026-06-11 Update README with additional documentation and CAD files
    Added extensive documentation and CAD files to README.
